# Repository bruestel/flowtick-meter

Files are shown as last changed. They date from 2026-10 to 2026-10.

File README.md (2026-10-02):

# flowtick-meter

**A battery-free optical reader for water meters with a scanning disc.**

Many mechanical water meters carry a small disc in their register that turns
with the flow (half mirror-bright, half black) so that a plug-in module can
count its revolutions. The vendor's pulse modules run on a glued-in lithium cell
and are thrown away when it is empty. flowtick-meter replaces such a module with
a 3D-printed case holding a **Vishay TCRT5000L** reflective sensor and an
**ESP32-C6**, powered over USB. Every bright/dark edge of the disc is one *tick*
of a fixed volume; the reading goes to **MQTT / Home Assistant** and a built-in
web interface.

<p align="center">
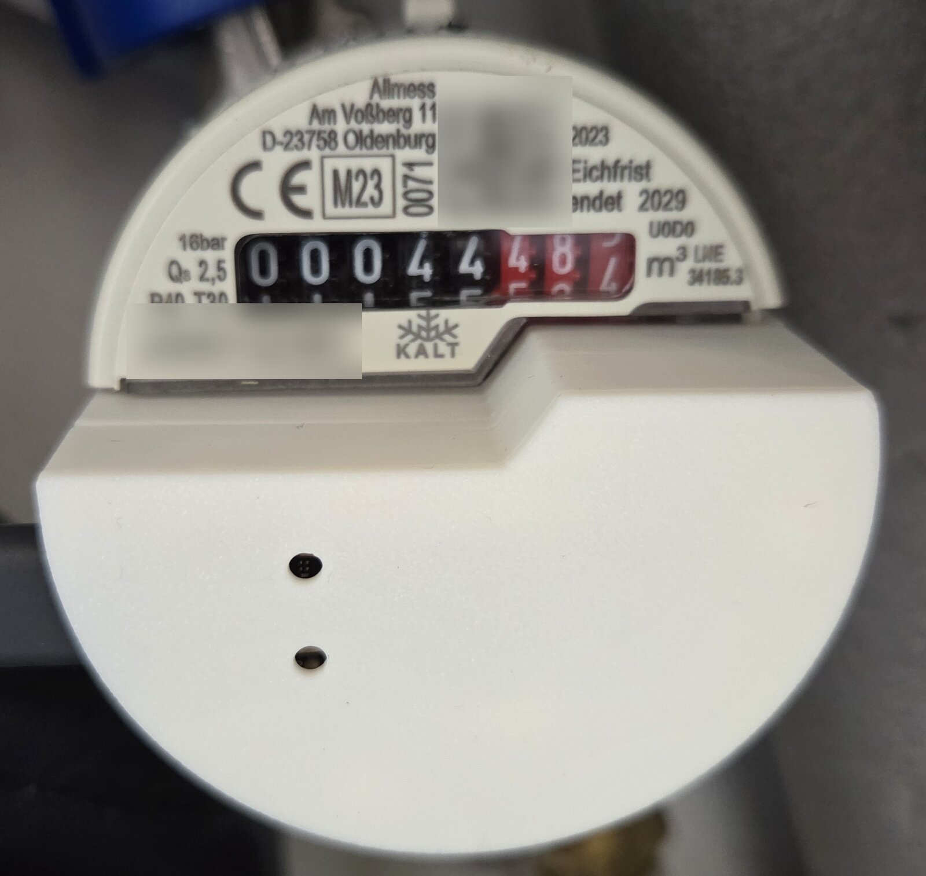
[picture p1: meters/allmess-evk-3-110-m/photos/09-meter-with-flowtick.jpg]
flowtick-meter mounted on an Allmess EVK 3/110 +m
  
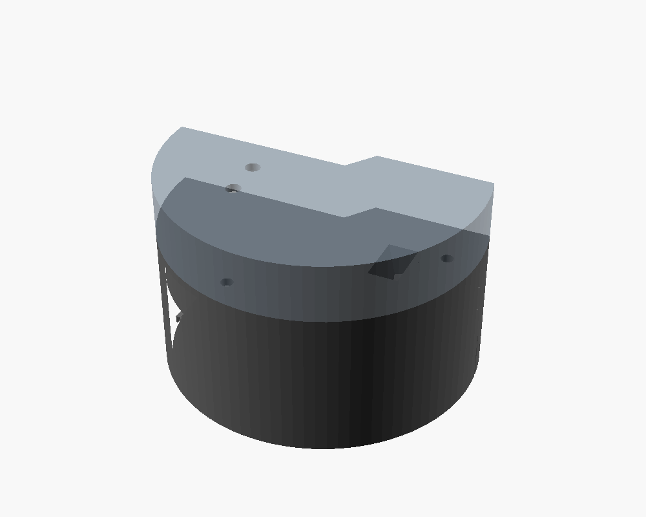
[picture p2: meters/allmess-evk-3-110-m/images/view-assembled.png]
Adapter and cap, CAD model
  
</p>

## How it works

The sensor over the chrome and the black sector, and the resulting signal

```mermaid
flowchart LR
  disc(["Scanning disc<br/>half chrome, half black"]) -- "IR light" --> sensor["TCRT5000L<br/>reflective sensor"]
  sensor -- "voltage" --> mcu["ESP32-C6<br/>ADC at 100 Hz"]
  mcu --> det{{"Edge detector<br/>hysteresis, dwell,<br/>plausibility"}}
  det -- "edge = 0.5 L" --> total["Reading<br/>and flow"]
  total --> ha["MQTT<br/>Home Assistant"]
  total --> web["Web UI"]
  total --> log[("Edge log<br/>in flash")]
```

The sensor sits a few millimetres above the disc. Chrome reflects the IR LED
into the phototransistor, black does not; the voltage swings by about 2.4 V.
The firmware turns that into edges, counts them and keeps the reading across
restarts. Details: [docs/how-it-works.md](docs/how-it-works.md).

One revolution of the disc on a real meter, as the built-in scope shows it:
chrome at ~3 V, black at ~0.5 V, both thresholds dashed, every detected edge
as a green line.

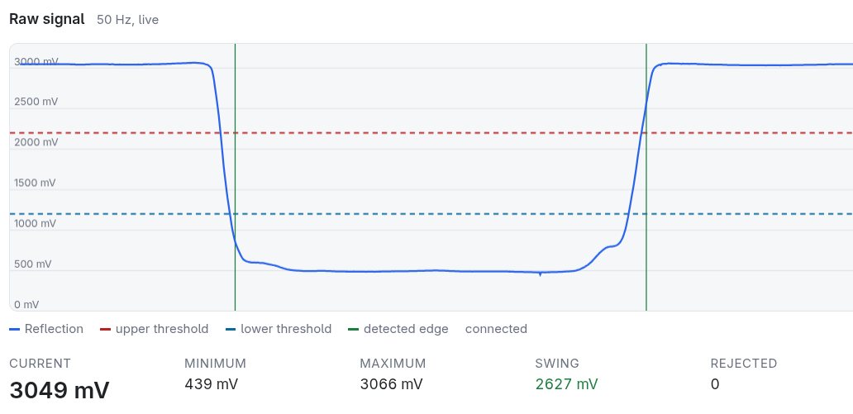
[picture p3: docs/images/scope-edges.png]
Live scope in the web interface: one revolution with two detected edges


## Features

- **Web interface**: reading, flow, water draws, a **live oscilloscope** of the
  raw sensor signal for tuning, all settings; every tab has its own URL.
- **Robust edge detector**: two thresholds (hysteresis), a dwell time against
  spikes, a minimum gap between edges, and a fault mode: a removed adapter or
  light falling in stops counting, and on return the detector resynchronises
  without inventing an edge.
- **Edge log**: every edge with its time in a flash ring that survives power
  cuts, written append-only so it does not wear out the flash; CSV export.
- **Reading kept safe**: saved once a minute when it changed and before every
  restart.
- **WiFi setup**: captive portal on first start; network changes are tested
  before they are stored, and the page follows the device to its new address.
- **OTA updates** with automatic rollback, from the web UI or `curl`.
- **MQTT** with `mqtt://` or `mqtts://` (built-in public CAs, own CA, or
  unchecked), optional login, **Home Assistant discovery**: meter reading for the
  energy dashboard, flow, a *Continuous flow* leak warning and a status entity
  with device diagnostics.
- **Time** from a configurable NTP server with a built-in fallback, timezone
  selectable.

## Supported meters

| Meter | Interface | Volume per edge | Status |
|---|---|---|---|
| [Allmess EVK 3/110 +m](meters/allmess-evk-3-110-m/) | `+m` module bay, optical scanning disc | 0.5 L | working |

The same module bay is used across the Allmess `+m` family, so other meters of
that family very likely fit the same case. Another meter? See
[docs/adding-a-meter.md](docs/adding-a-meter.md).

## Quick start

1. **Get the parts**: ESP32-C6 Super Mini, TCRT5000L, two resistors, black
   PETG; list in [docs/hardware.md](docs/hardware.md).
2. **Solder** the sensor circuit: [docs/hardware.md](docs/hardware.md),
   schematic in [docs/schematic.png](docs/schematic.png).
3. **Print the case** for your meter from [`meters/`](meters/), e.g.
   [meters/allmess-evk-3-110-m/](meters/allmess-evk-3-110-m/).
4. **Build and flash** the firmware: [docs/firmware.md](docs/firmware.md).
5. **Connect** to the `flowtick-xxxxxx` network, enter your WiFi, then
   **tune** thresholds and set the reading: [docs/tuning.md](docs/tuning.md).
   For a supported meter the tested values can be used as they are.

## Repository layout

```
.
├── docs/                  how it works, hardware, firmware, tuning, new meters
├── firmware/              ESP-IDF firmware (C++20, PlatformIO) and web UI
└── meters/
    └── allmess-evk-3-110-m/
        ├── cad/           OpenSCAD source of the case
        ├── stl/           ready-to-print parts
        ├── images/        renders
        └── photos/        photos of the build and the meter
```

## Contributing

New meters, fixes and measurements are welcome, see
[CONTRIBUTING.md](CONTRIBUTING.md).

## Licence

[Apache License 2.0](LICENSE) for everything in this repository: firmware, CAD
models, documentation and images. Copyright 2026 Jonas Brüstel. Firmware images
also contain third-party components, listed in
[THIRD-PARTY-NOTICES.md](THIRD-PARTY-NOTICES.md).

flowtick-meter is not affiliated with or endorsed by any meter manufacturer.
Brand and model names are used only to say which meter a part fits.

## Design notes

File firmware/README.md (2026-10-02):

# flowtick-meter firmware

ESP-IDF firmware for the flowtick-meter reading head: an ESP32-C6 samples a
reflective sensor over the scanning disc of a water meter, counts the edges
and publishes reading, flow and status over a web interface and MQTT.

Networking, configuration, MQTT, the web interface, OTA with rollback,
watchdog, coredump and the BOOT-button recovery are infrastructure taken from
the author's bsh-dbus-idf project; the meter, the edge log and the API on top
are this project's own.

This file is the developer view. For users:

* [../docs/firmware.md](../docs/firmware.md): web interface, MQTT, LED, edge log
* [../docs/tuning.md](../docs/tuning.md): thresholds, edge filter, volume per edge
* [../docs/hardware.md](../docs/hardware.md): board, sensor circuit, wiring

## Building

```bash
pio run -e supermini-c6            # build
pio run -e supermini-c6 -t upload  # flash
pio device monitor
```

Flash size is pinned to 4 MB (`board_upload.flash_size` /
`board_build.flash_size`); without it the upload writes an 8 MB header and the
bootloader asserts. Flash directly, not behind a chain of USB hubs.

The firmware version (web UI, MQTT status, Home Assistant) comes from
`git describe --tags --always --dirty` in a git checkout, and from
`version.txt` otherwise (e.g. a source archive). Bump it with every release.

The project name in the image (`project(flowtick-meter)` in `CMakeLists.txt`)
is checked on OTA: an image of another project is refused.
`same_project()` in `app_web` also accepts the former name `water-meter`, so
devices flashed before the rename update over the air.

Afterwards, OTA from the web UI or:

```bash
curl -X POST -H 'Content-Type: application/octet-stream' \
     --data-binary @.pio/build/supermini-c6/firmware.bin http://<ip>/api/v1/ota
```

ESP-IDF 6.0.1 via `espressif32@7.0.1`. On the first build the component
manager fetches cJSON, esp-mqtt and mDNS, pinned by `dependencies.lock`.

Configuration is **not** compiled in: on first boot the device opens its own
WiFi network and serves a captive portal. Enter WiFi and MQTT there; after
that everything goes through the web interface or OTA.

## Components

| Component | Purpose |
|---|---|
| `app_net` | WiFi station with AP fallback, captive portal, scan and test-before-store connect, transmit power, SNTP (configurable server + built-in fallback, timezone) |
| `app_config` | settings in NVS, PBKDF2 password (stored as one atomic entry) |
| `app_mqtt` | MQTT / MQTTS (built-in CA bundle, own CA or unverified), HA auto-discovery, LWT |
| `app_web` | HTTP, auth, **OTA with rollback**, WebSocket, the REST API |
| `meter` | ADC, edge detection, register, leak watch, NVS |
| `edgelog` | append-only ring of edges in the `edgelog` flash partition |
| `src/` | `main.cpp` wiring, board pins, status LED, diagnostics, BOOT-button recovery, the trial period of a new image (`probation`) |

WiFi power save is off while the scope runs. The default device name is
`flowtick-xxxxxx` from the last three MAC bytes; the Home Assistant device
identity stays `water-meter-xxxxxx` (`appcfg::device_id()`) so devices from
before the rename keep their entities.

## Edge detector

Hysteresis alone is not enough. On top of `thr_hi_mv`/`thr_lo_mv`
(defaults 2200/1200 mV, tuned for the first meter; see
[../docs/tuning.md](../docs/tuning.md)):

* **dwell** (`dwell_ms`, default 80): a crossing counts only once the signal
  has stayed beyond the threshold that long; shorter ones count as `rejected`.
* **minimum gap** (`min_edge_ms`, default 150): faster edges are physically
  impossible (Q4 = 3.1 m³/h at 0.5 L/edge is 0.58 s apart).
* **plausibility**: outside 50..3250 mV for 0.5 s the mode becomes `Fault`
  and nothing counts; after 2 s of plausible signal it goes to `Resync`,
  which waits until the signal is clearly beyond one threshold for `dwell_ms`,
  takes that as the current sector without counting, then `Run`. Between the
  thresholds nothing is decided, so a half-fitted adapter or a disc parked on
  the boundary costs at most one missed edge, never a phantom one.
* **pause** (`POST /api/v1/meter/pause`): `Paused`, e.g. to take the adapter
  off; resuming goes through `Resync`, so reattaching cannot produce an edge.

The detector also starts in `Resync`, so a reboot never creates a phantom
edge. Volume per edge (`ml_per_edge`, default 500) depends on the meter: the
first one turns its disc once per litre, and both edges count.

**Leak watch:** a *run* is a series of edges with never 10 minutes of quiet
between them. Once the edges of one run span an hour, `continuous_flow` is
set (published as a `binary_sensor`); 10 quiet minutes clear it. The flow
figure alone cannot do this: with 0.5 L per edge and a 10 s window it is 0 or
≥ 3 L/min, so a dripping tap stays invisible in it.

## Edge log

The `edgelog` partition (256 KB at 0x380000) is a ring of 4 KB sectors of
8-byte slots: `type | 48-bit payload | crc8`. Edges are stored as uptime ms;
one boot record per boot and one epoch record once SNTP has set the clock,
so edges before time sync still get wall-clock time. Append-only, a sector is
erased only when the ring comes round again, a torn slot fails its crc and is
skipped. Capacity ~32 700 edges (~16 m³). Writes go through a queue to a task
of their own, so the sampler never blocks on flash.

## The live oscilloscope

The WebSocket carries ADC samples from a ring buffer with replay: a reconnect
continues the graph instead of clearing it. Opening the Tuning tab starts a
fresh trace (it asks for no replay), so nothing from before is shown.

In the **Tuning** tab you see the raw signal in real time, with both
thresholds as dashed lines, every detected edge as a vertical stroke and
rejected crossings marked at the top. The stream only runs while the tab is
open, at 50 Hz.

What it took to make it smooth:

* up to 10 samples (100 ms) bundled into one JSON array frame, `TCP_NODELAY`
  set in the pre-handshake callback;
* every client gets its own refcounted payload copy via
  `httpd_ws_send_data_async`, at most 8 in flight; a failed send closes the
  client;
* `send_wait_timeout` 3 s (was 20) and TCP keepalive, so a stalled browser
  tab can block neither other clients nor OTA;
* WiFi power save off while the scope is on;
* the UI plays out on its own clock 300 ms behind the device timestamps and
  draws against a time axis; a watchdog reconnects after 3 s of silence.

## Web UI

Tabs **Meter** (reading, flow, water draws from the edge log with CSV export),
**Tuning** (scope, current/min/max/swing/
rejected, thresholds, edge filter, volume per edge), **Settings** (pause card,
match register, WiFi dialog, MQTT, radio transmit power with Apply, time server
and timezone, device name, auth) and
**System** (status LED legend, OTA, state, restart, factory reset).

WiFi change is test-before-store: from the setup network the device tries the
credentials, reports the new IP in `net.test`, stores and restarts after
30 s. From an existing network it probes the new one, returns to the old one
to report the IP (the networks may be on different subnets), then commits
after 12 s. The UI redirects to the new IP in both cases.

## Time

SNTP starts once the station has an address. Server from the settings
(default `pool.ntp.org`), with a built-in one always behind it
(`time.cloudflare.com`, or `pool.ntp.org` when that is the configured one);
left empty, both slots are built in. Synced every hour. The device counts in
UTC; the timezone (IANA name for the browser, POSIX rule for `TZ`) only sets
how times are shown. The server that last answered is reported in
`/info` → `time.server` and in the MQTT status.

## MQTT

Topic root `<base>` from the settings, default `flowtick/<device name>`.

| Topic | Retained | Content |
|---|---|---|
| `<base>/status` | yes | `online` / `offline` on change and every minute; LWT. `offline` while the detector is in `Fault`, and ~45 s after the device vanishes (keepalive 30 s) |
| `<base>/state/total` | yes | reading in m³, every 10 s |
| `<base>/state/flow` | yes | L/min over the last 10 s, every 10 s |
| `<base>/state/continuous_flow` | yes | `On` / `Off`, every 10 s |
| `<base>/sensor` | yes | JSON every minute: `mode`, firmware, uptime, boot reason, heap, network (hostname, SSID, RSSI, channel, TX power, MAC, IP, netmask, gateway, DNS), time (synced, server, timezone) |

With discovery on, Home Assistant gets one device with *Meter reading*
(`water`, `total_increasing`), *Flow*, *Continuous flow* (`problem`) and a
diagnostic *Status* whose attributes are the JSON above. Values are always
published; whether they are current is what `<base>/status` says; an empty
retained payload would erase the reading at the broker.

## Status LED

One LED (GPIO15), pattern repeats every 10 s: 1 flash online, 2 flashes WiFi
configured but not connected, 3 flashes online but sensor signal
implausible; plus one short flash per edge. Solid = booting / erase armed,
5 Hz = setup network, mostly-on = OTA, 10 Hz = fatal. See
[`src/indicator.h`](src/indicator.h).

## API

All endpoints honour the configured basic auth (off by default).

| Method | Path | Purpose |
|---|---|---|
| GET | `/` | the web interface |
| GET | `/api/v1/info` | overall status: `firmware`, meter (incl. `online`, `mode`, `rejected`, `dwell_ms`, `min_edge_ms`, `continuous_flow`, `flow_run_s`), net (incl. `test`), system (`tx_power_dbm`, `ntp_server`, `tz_name`), time, mqtt |
| GET | `/api/v1/meter` | reading, flow, raw value |
| POST | `/api/v1/meter/total` | `{"m3":44.2670}`: match the mechanical register |
| POST | `/api/v1/meter/pause` | `{"on":true\|false}`: stop / resume counting |
| GET | `/api/v1/edges?limit=N` | edge log, oldest first: `[[t_ms, synced, boot], …]` (default 2000, `0` = all) |
| DELETE | `/api/v1/edges` | erase the edge log |
| GET | `/api/v1/tuning` | current tuning |
| POST | `/api/v1/tuning` | `{"thr_hi_mv":…,"thr_lo_mv":…,"ml_per_edge":…,"dwell_ms":…,"min_edge_ms":…}`, missing fields unchanged |
| POST | `/api/v1/minmax/reset` | restart the swing window |
| POST | `/api/v1/scope` | `{"on":true}`: live stream |
| GET | `/api/v1/samples?since=N` | pull the ring instead of having it pushed |
| GET | `/api/v1/ws` | WebSocket: sample stream |
| GET | `/api/v1/wifi/scan` | networks in range, strongest first |
| POST | `/api/v1/wifi/connect` | `{"ssid":…,"password":…}`: test, then store (see above); progress in `/info` → `net.test` |
| GET/POST | `/api/v1/config/mqtt` | MQTT settings: `enabled`, `host`, `port`, `tls`, `tls_insecure`, `ca_cert` (empty with TLS = built-in CA bundle), `client_id`, `auth`, `user`, `password` (absent = unchanged), `base`, `discovery`, `discovery_prefix` |
| POST | `/api/v1/config/device` | `{"name":…}`: device / host name |
| POST | `/api/v1/config/auth` | `{"enabled":…,"user":…,"password":…}`: web UI auth |
| POST | `/api/v1/config/system` | `{"tx_power_dbm":17}`: transmit power (0 = maximum); `{"ntp_server":"pool.ntp.org","tz_name":"Europe/Berlin","tz_posix":"CET-1CEST,M3.5.0,M10.5.0/3"}`: time server (empty: built-in only; a built-in fallback always stands behind it) and timezone (name and POSIX rule together) |
| POST | `/api/v1/ota` | firmware.bin as `application/octet-stream`; header `X-Confirm: ui` when the caller will confirm the new image itself |
| GET | `/api/v1/ota/status` | running slot and version, `pending_verify`, `ui_confirmed`, and during the trial period `probation` (`uptime`, `sampler`, `network`, `web_server`, `page_needed`, `page`, `left_s`, `window_s`) |
| POST | `/api/v1/ota/confirm` | the update page confirms the new image (see [../docs/firmware.md](../docs/firmware.md#updates-and-rollback)) |
| GET | `/api/v1/selftest` | `{"ok":true}`, answered only over loopback for the image's self-test; 404 from anywhere else |
| POST | `/api/v1/restart` | restart |
| POST | `/api/v1/reset` | factory reset |
| GET | `/api/v1/health` | tasks, stack, heap, reset reason |
| GET/DELETE | `/api/v1/coredump` | download / erase the stored coredump |

## Decisions

**Oneshot ADC instead of continuous/DMA.** At Q3 = 2.5 m³/h the flow is at most
41.7 L/min; at 0.5 L per edge that is ~1.4 edges per second. 100 Hz is a
factor of 70 above that. DMA would mean a ring buffer and interrupt handling
for a signal that changes about once a second.

**Median over 8 samples, not the mean.** The median kills single outliers
without smearing the edge. A mean would blur exactly the edge that matters.

**`CONFIG_FREERTOS_HZ=1000`.** Not optional. At the default of 100 Hz the tick
resolution would equal the sampling period, and the jitter would be 100 %.

**Reading written to NVS once a minute if it changed, not per pulse.** Per
pulse the flash would be worn out within months; once a minute is about two
erases per NVS page and day even with water running non-stop (~135 years to
100 000 cycles). Cost: at most a minute of consumption on a power cut. Before
every deliberate restart (OTA, restart, recovery) it is written as well.

**Reading saved before every deliberate restart.** A shutdown handler in
`meter` writes it from `esp_restart()`. Without it every OTA lost up to the
last save interval, and Home Assistant reads a reading that went backwards
(`total_increasing`) as a meter swap.

**Reading as `uint64` in millilitres.** `uint32` would overflow at ~4,294 m³.
For a project meant to outlive several meter generations, not a theoretical
problem.

**Thresholds are rejected if `thr_hi <= thr_lo`.** Such a hysteresis is none:
it would flip on every sample and drive the counter up by cubic metres within
seconds. Better to reject than to puzzle later over where the consumption came
from.

## Pinout

See [`src/board.h`](src/board.h). In short: ADC on **GPIO1**, status LED
GPIO15, BOOT GPIO9, IR LED tied to 3V3.

On the C6, ADC1 sits on GPIO0..GPIO6 and there is no ADC2; of those, only
GPIO0..GPIO3 are broken out on the Super Mini and free of boot duties.

`LED_ACTIVE_LOW` is verified as `false` (active high) on this board. The Super Mini clones are not consistent
about it. If the LED blinks inverted, it is this switch and nothing else.

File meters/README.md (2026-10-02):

# Meters

One folder per meter model. Each folder holds what is specific to that meter:
the case that fits its module bay and the sensor values that make it read
reliably. Everything else (circuit, firmware, tuning) is shared and lives in
[`docs/`](../docs/) and [`firmware/`](../firmware/).

## Supported

| Folder | Meter | Volume per edge | R1 / R2 | Status |
|---|---|---|---|---|
| [allmess-evk-3-110-m](allmess-evk-3-110-m/) | Allmess EVK 3/110 +m (cold water) | 0.5 L | 560 Ω / 1.56 kΩ | working |

## Folder structure

```
meters/<vendor>-<model>/
├── README.md     meter data, module bay, measurements, tested values
├── cad/          parametric source of the case (OpenSCAD preferred)
├── stl/          exported parts, ready to print
├── images/       renders of the case
└── photos/       reference photos (metadata stripped)
```

Folder names are lower case, words separated by hyphens:
`<vendor>-<model>`, e.g. `allmess-evk-3-110-m`.

How to add one: [docs/adding-a-meter.md](../docs/adding-a-meter.md).

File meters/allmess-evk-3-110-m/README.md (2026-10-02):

# Allmess EVK 3/110 +m

Cold water meter by Allmess with a **+m module bay**: a standard slot for a
plug-in communication module (pulse, M-Bus or wireless M-Bus), fitted without
removing the meter or touching its calibration. As delivered, the bay holds a
**blank module** ("Leermodul") that is just a dust cover. The flowtick-meter
case replaces it: a printed adapter in the shape of the blank module, carrying
the reflective sensor over the scanning disc and the ESP32-C6 Super Mini in
front of it.

**Status:** printed and running. The snap fit was verified with fit tests on
the real meter, and the counting matches the mechanical register.

| flowtick-meter on the Allmess EVK 3/110 +m | Adapter and cap, assembled |
|---|---|
| on the meter | the CAD model |

## The meter

| | |
|---|---|
| Meter | Allmess EVK 3/110 +m, cold water |
| Interface | +m module bay, optical (no magnet, no reed contact) |
| Scanning disc | under the clear window to the right of the roller register, **half chrome, half black** |
| Disc ratio | dial marked **x0,0001**: 1000 revolutions per m³ = **1 L per revolution** |
| Edges | 2 per revolution (chrome→black, black→chrome) = **0.5 L per edge** |
| Original pulse module (PM +m) | at best 1 L per pulse, battery for ~13 years |

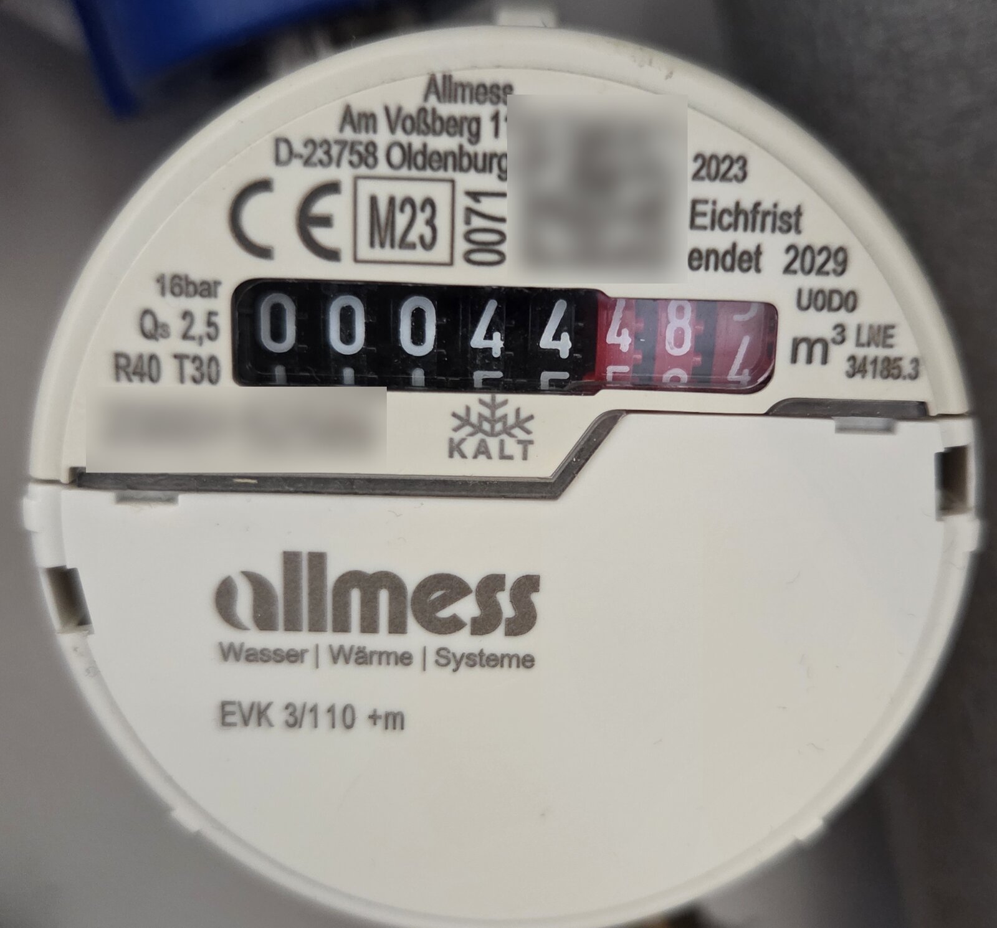
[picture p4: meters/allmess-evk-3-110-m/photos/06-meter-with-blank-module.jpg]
With the blank module
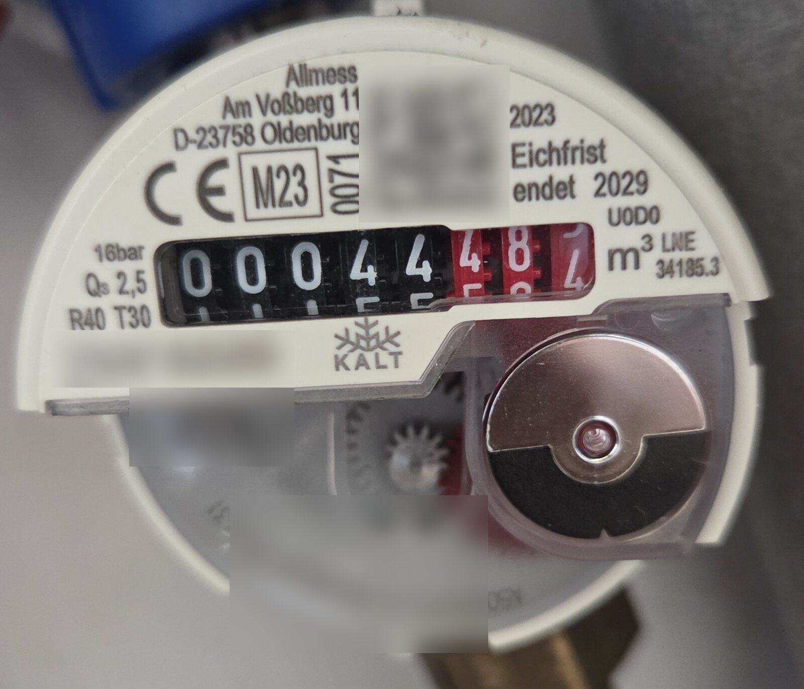
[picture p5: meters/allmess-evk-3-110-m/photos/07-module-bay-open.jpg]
Module bay open
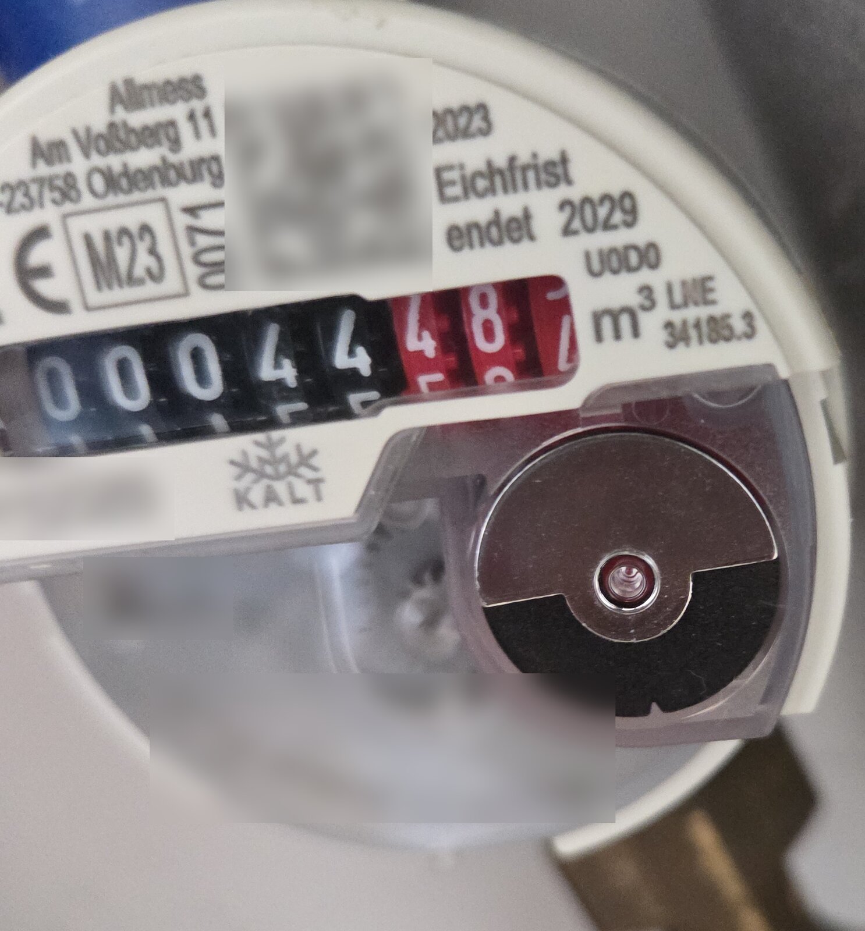
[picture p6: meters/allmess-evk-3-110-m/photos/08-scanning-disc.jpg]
The scanning disc
|  |  |  |
|---|---|---|
| as delivered, with the blank module | blank module removed: the disc sits under the clear window | the disc, half chrome, half black |

The +m register is the same across the Allmess family (EVK, EV, WTZ,
System-V, System-MK, AMES measuring capsule): same bay, same snaps, same
disc. A case built once also fits the meter that replaces this one when its
calibration period runs out.

**Before you start:** taking the blank module off tears the name plate at its
perforation and cannot be undone. If the meter belongs to the utility or the
landlord, your own hardware in the module bay may count as tampering with a
calibrated device; ask first.

## The module bay

The adapter replaces the blank module that sits in the bay when no
communication module is fitted. Its outline is a copy of that blank module,
taken from a flatbed scan. Only the round wall touches the meter; the clear
window over the disc pokes past the straight edge, which is what the nose of
the case is for. All dimensions are parameters in
[`cad/housing.scad`](cad/housing.scad).

## The case

Two parts, joined by two screws, both printable **without support**. Source:
[`cad/housing.scad`](cad/housing.scad) (OpenSCAD, fully parametric).

| Part | `part=` | What it does | Print orientation |
|---|---|---|---|
| **Adapter** | `adapter` | copy of the blank module: round wall, snap tongues, sensor sleeve | front face down |
| **Cap** | `cap` | compartment for the Super Mini, sits on the front of the adapter | lid down |

| Adapter front | Without the cap | Laid out for printing |
|---|---|---|
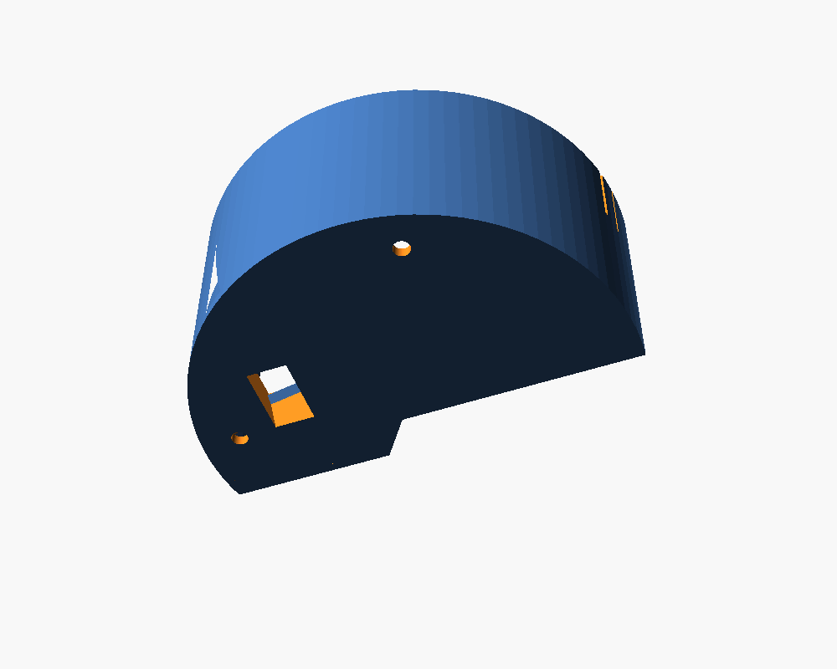
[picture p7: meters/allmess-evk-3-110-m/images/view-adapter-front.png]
Adapter front
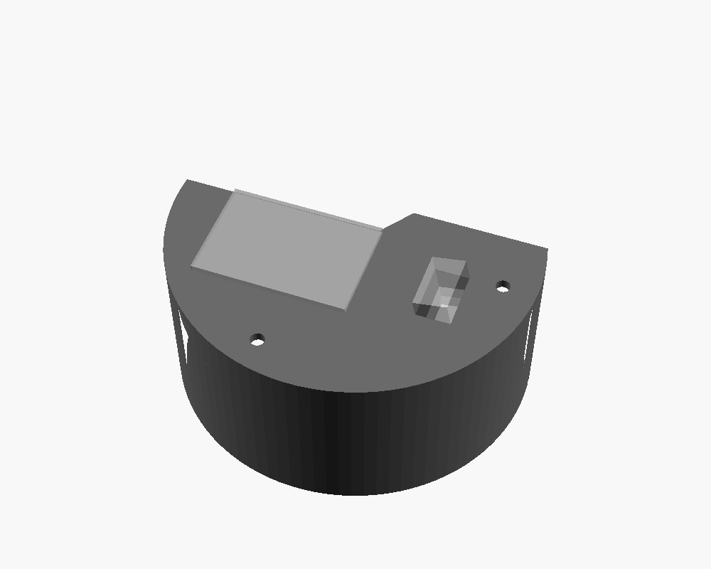
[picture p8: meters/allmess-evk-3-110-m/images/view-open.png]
Board and sensor outlines
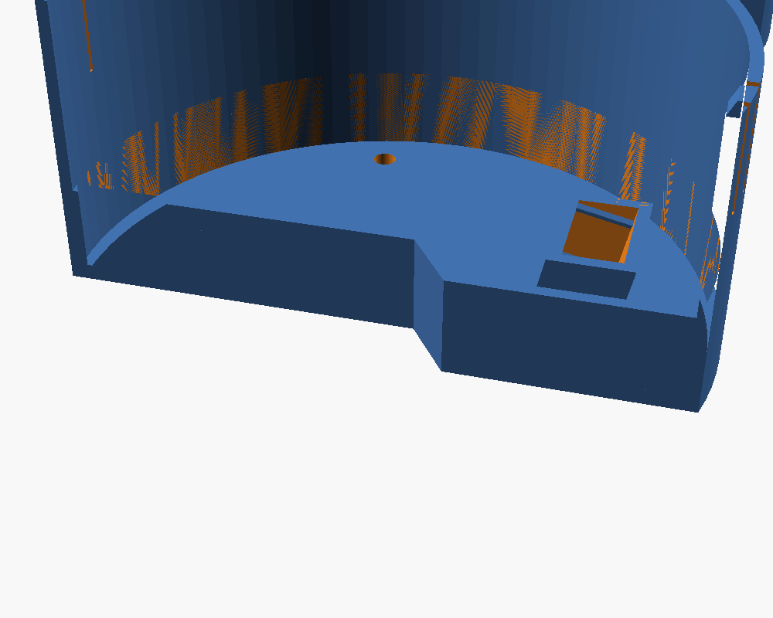
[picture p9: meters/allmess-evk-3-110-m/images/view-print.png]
Print layout
|  |  |  |

### Adapter

* **6 mm deeper than the original** (`lift`, 29.5 instead of 23.5 mm). The
  front plate moves out; the rim against the meter and the snap tongues stay
  where the original had them.
* **Sensor sleeve** in the 6 mm gained, from the front plate backwards, ending
  where the floor of the original was, right in front of the window. The
  TCRT5000L peaks at 2.5 mm and the window is ~5 mm behind the original front
  plate, so the sensor has to reach in. It sits 4.5 mm below the disc centre
  (`sensor_off`, `sensor_dir = -90`), lens axis radial, so both lenses see the
  rotating sectors, and is **tilted 12°** about the lens axis (`tilt`) so the
  direct reflection off the window misses the phototransistor.
* **Stop in the sleeve:** two 45° wedges (`stop`, 1 mm) at the short ends. The
  narrow lens end (~6.8 mm) passes, the shoulders of the TCRT5000L rest on
  them. The window can push the sensor back, so it finds its own distance.
* **Press fit**, 0.05 mm undersize per side (`press`); find yours with the slot
  test.
* **Rim** along the straight edge, the chamfer and the nose: 4 mm + `lift` from
  the front.
* **Snap tongues** 10 mm long (`slot_depth`; the original ~4 mm ones broke)
  with a 0.8 mm catch (`catch_h`) and a lead-in ramp. The left one sits 1 mm
  further towards the straight edge than the scan, from fit tests.

Switched off, but still in the model as parameters:

| Parameter | What | Why off |
|---|---|---|
| `inner_wall_on` | straight inner wall as on the original | the rim is enough; it gets in the way when fitting |
| `ribs_on` | the three ribs inside | switch on if the adapter wobbles |
| `pocket_wall` | cup around the pocket | the case is black anyway; a slightly misplaced cup would sit on the window |
| `release_windows` | windows over the snap tongues | cannot be reached under the cap |

### Cap

* The Super Mini (26.04 × 18 mm) lies across, **components towards the lid**,
  USB-C to the left, beside the sensor rather than over it; the antenna end
  faces the sensor.
* It hangs in **four corner brackets** from the lid and snaps in past small
  lips (`lip = [0.3, 1.2]`: 0.3 mm undercut, 1.2 mm ramp), 5.3 mm below the
  lid (`board_stand`, room for the plug overmould). Ribs from the lid support
  both pin rows, broken where wires are soldered (GND, 3V3, GPIO1).
* The board sits as far left as the round allows (`board_pos`), leaving 7.2 mm
  between board and sensor sleeve for R1, R2 and C1.
* Opening for the USB-C plug in the left wall (`usb_notch`, 13 × 10 mm), holes
  in the lid for BOOT and RST. The status LED shines through the lid.

### Screws

2 × **M2 × 8 self-tapping**, **from behind** through the adapter front into
bosses in the cap (`screws`): pilot hole 1.7 mm, clearance 2.4 mm, pan or
cheese head up to 4.2 mm (no countersink). The heads sit hidden inside the
adapter and the front stays flat; the price is that the screws go in before
the adapter goes onto the meter.

### Key parameters

| Parameter | Value | Meaning |
|---|---|---|
| `R` | 31.75 | outer radius |
| `D0`, `lift` | 23.5, 6.0 | original depth, extra depth for the sensor sleeve |
| `edge_y` | 2.5 | straight edge above the centre |
| `pocket_c` | [17.83, −2.79] | disc centre |
| `sensor_off`, `tilt` | 4.5, 12 | sensor offset from the disc centre, tilt about the lens axis |
| `press` | 0.05 | sensor slot undersize per side |
| `snap_right`, `snap_left` | see scad | slot and tongue extents along y |
| `slot_depth`, `catch_h` | 10, 0.8 | tongue length, catch height |
| `board_pos`, `board_stand` | [−21.0, −18.8], 5.3 | board corner, lid to board |
| `screws` | [[−7, −25.5], [26, −2]] | screw positions |

## Printing

| | |
|---|---|
| Material | **PETG, black** |
| Layer height | 0.15–0.20 mm |
| Perimeters | **4** |
| Infill | 30 % |
| Support | **none** (adapter front down, cap lid down) |

PETG because the meter pit is damp and can get warm, PLA creeps under
constant load, and PETG is tougher at the snap tongues. Black and 4 perimeters
because many "black" filaments are translucent in the infrared: hold a print
against a bright torch, and if light comes through, print thicker or paint the
inside matt black.

### Print the test parts first

| `part=` | What | What for |
|---|---|---|
| `slot-test` | three sensor slots, undersize −0.05 / 0.05 / 0.15 mm, marked with 1/2/3 notches | the right one takes the sensor with firm pressure and holds it upside down; put its value into `press` |
| `snap-test` | the lowest ring of the adapter with both snap tongues | prints in minutes; try it on the real meter and tune `catch_h` and the tongue positions |

### Rendering the STLs

Ready-made STLs are in [`stl/`](stl/). To render them yourself (tested with
OpenSCAD 2021.01):

```sh
cd meters/allmess-evk-3-110-m
openscad -o stl/adapter.stl   -D 'part="adapter"'   cad/housing.scad
openscad -o stl/cap.stl       -D 'part="cap"'       cad/housing.scad
openscad -o stl/slot-test.stl -D 'part="slot-test"' cad/housing.scad
openscad -o stl/snap-test.stl -D 'part="snap-test"' cad/housing.scad
```

`part="print"` lays out adapter and cap side by side, `both` shows them
assembled, `open` without the cap (board and sensor as outlines).

## Assembly

1. Wire the sensor and resistors, see [hardware](../../docs/hardware.md).
2. Push the board into the cap until it snaps in past the lips.
3. Push the sensor into the sleeve of the adapter from the front, lenses
   first, until it rests on the wedges. Lead the wires to the board.
4. Put the cap on and drive the two M2 × 8 **from behind** through the adapter
   front into the bosses.
5. Push the adapter onto the register until both tongues snap in. The window
   pushes the sensor back in its sleeve until it touches.

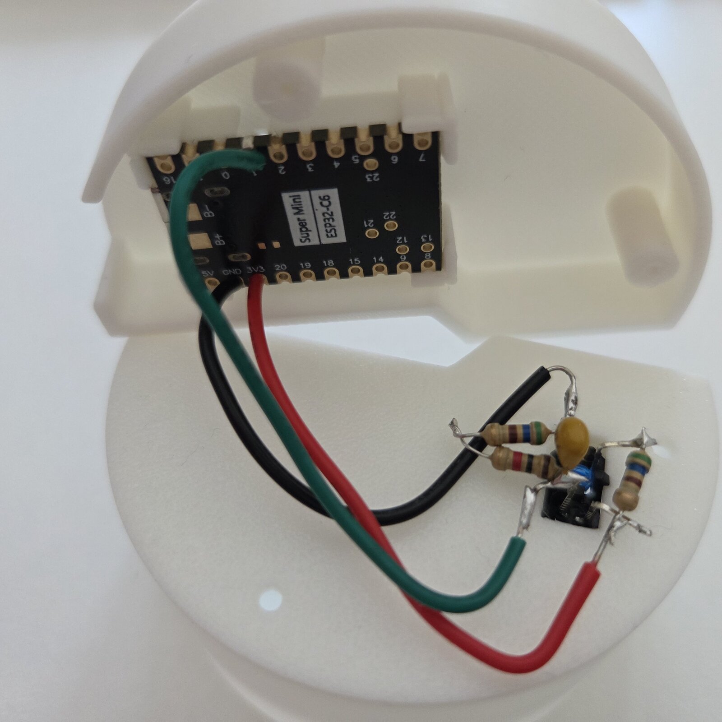
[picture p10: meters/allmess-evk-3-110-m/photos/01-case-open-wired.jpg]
Case open, wired
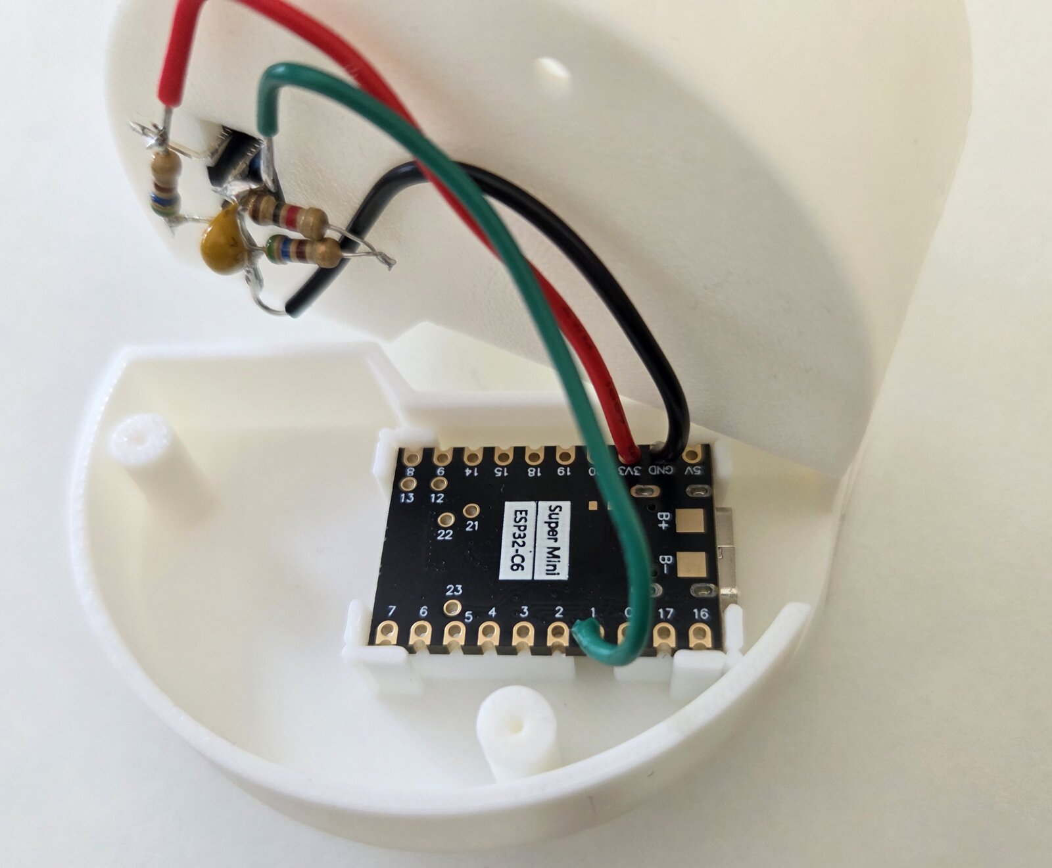
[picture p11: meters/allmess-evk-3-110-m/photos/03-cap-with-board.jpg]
Cap with the board
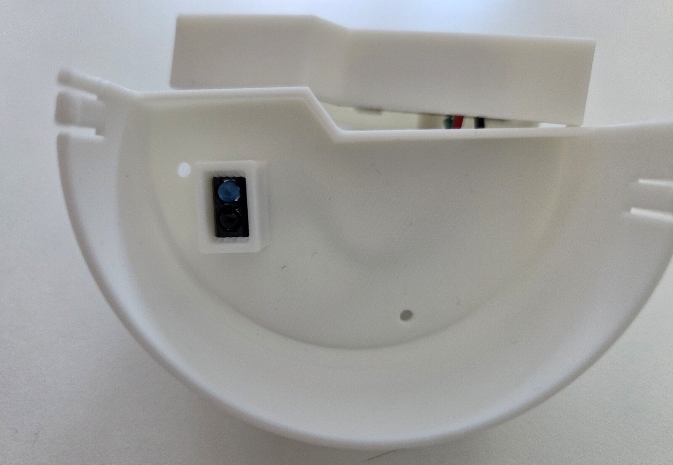
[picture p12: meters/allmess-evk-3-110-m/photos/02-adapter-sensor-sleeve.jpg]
Sensor in its sleeve
|  |  |  |
|---|---|---|
| wired: board in the cap, sensor with R1/R2 in the adapter | board snapped in between the corner brackets | sensor sitting in the sleeve |
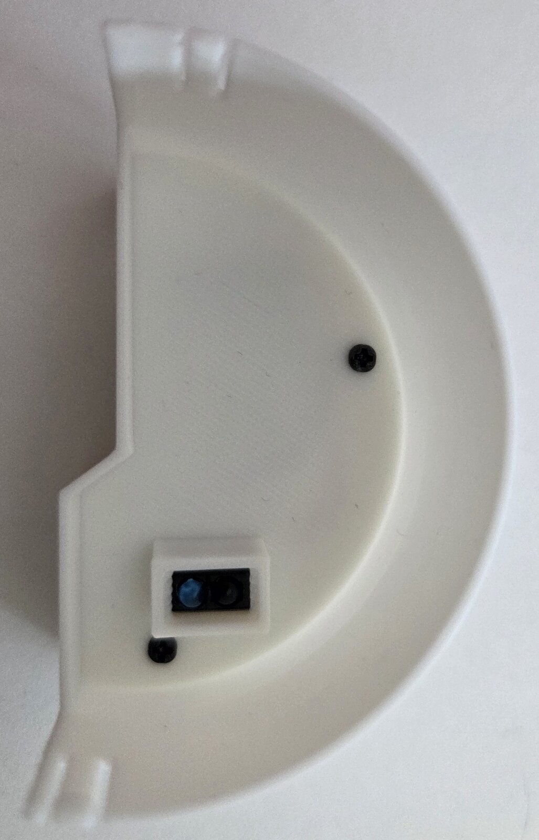
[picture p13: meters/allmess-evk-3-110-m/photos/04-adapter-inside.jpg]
Adapter, inside
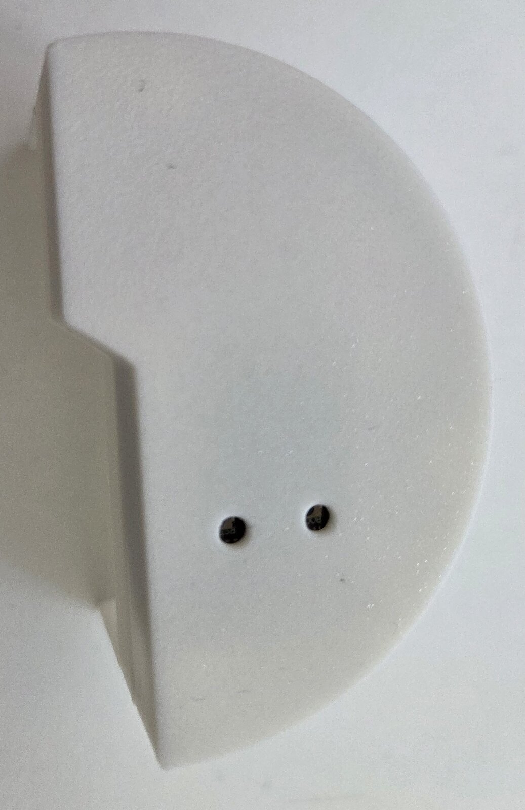
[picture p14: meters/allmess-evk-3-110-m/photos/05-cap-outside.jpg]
Cap, outside
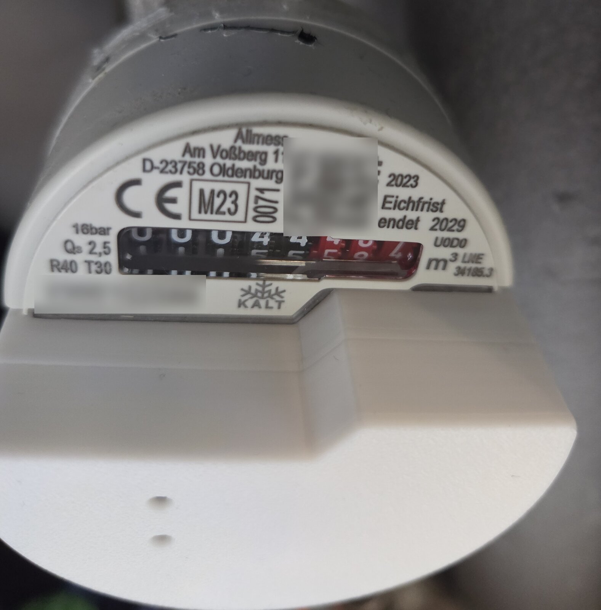
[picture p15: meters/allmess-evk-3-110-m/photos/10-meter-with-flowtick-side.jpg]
Mounted, side view
|  |  |  |
| adapter from behind: sensor sleeve and the two screws | cap from outside: holes for BOOT and RST | mounted on the meter |

To take it off again, pause counting in the web interface first, see
[tuning](../../docs/tuning.md).

## Tested values

**No changes needed for this meter**: these are the firmware defaults.

| | |
|---|---|
| R1 (IR LED series) | 560 Ω |
| R2 (phototransistor emitter) | 1.56 kΩ (1 kΩ + 560 Ω in series) |
| Signal, black sector | ~500 mV |
| Signal, chrome sector | ~2900 mV |
| Swing | ~2.4 V |
| Thresholds | 2200 / 1200 mV |
| Dwell | 80 ms |
| Minimum gap between edges | 150 ms |
| Volume per edge | 0.5 L |

Scope on this meter: one revolution, swing 2627 mV, no rejected crossings

How these were found, and what to change for another meter, is in
[hardware](../../docs/hardware.md) and [tuning](../../docs/tuning.md).

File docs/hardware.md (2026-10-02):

# Hardware

The electronics are the same for every meter: an ESP32-C6 Super Mini and a bare
Vishay TCRT5000L reflective sensor, plus two resistors. Only the two resistor
values and the printed case change from meter to meter.

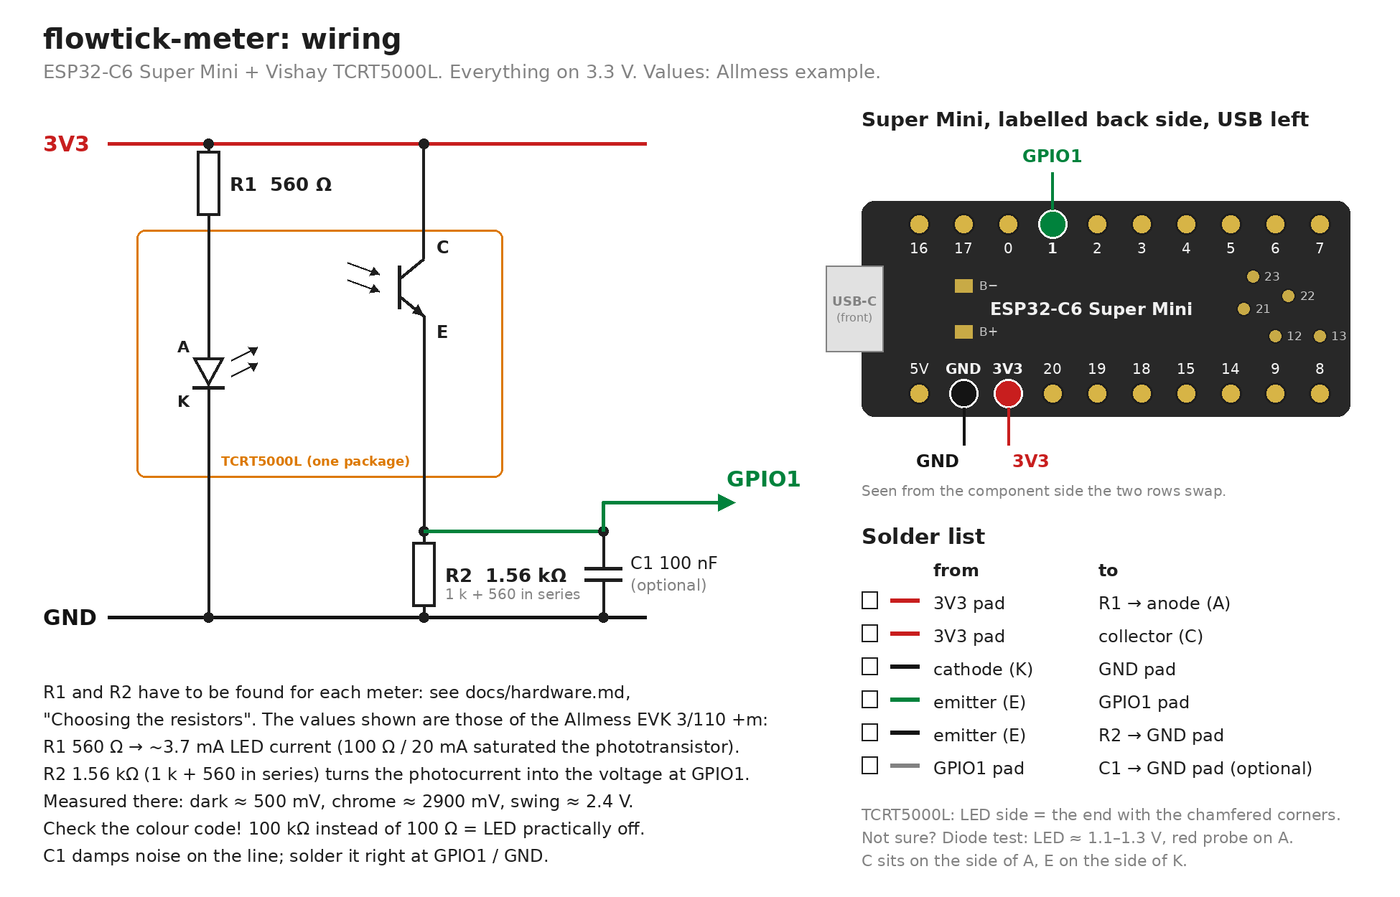
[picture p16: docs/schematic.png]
Circuit, Super Mini pads and solder list


Generated by [`schematic.py`](schematic.py) (`cd docs && python3 schematic.py`,
needs Pillow and the DejaVu fonts). The values shown are those of the
[Allmess EVK 3/110 +m](../meters/allmess-evk-3-110-m/README.md).

## Circuit

* **LED branch:** 3V3 → **R1** → anode (A) → cathode (K) → GND
* **Transistor branch:** 3V3 → collector (C) → emitter (E) → **GPIO1**, and
  from the emitter **R2** to GND
* **C1** (100 nF, optional) right at the board between GPIO1 and GND

**Signal direction:** the bright (chrome) sector reflects a lot, the
phototransistor conducts more, and the voltage at GPIO1 rises. The dark sector
gives a low voltage. The firmware turns every crossing between the two into an
edge; see [tuning.md](tuning.md).

**Everything runs on 3.3 V.** The bare TCRT5000L has no "operating voltage":
it is an IR LED and a phototransistor. The "5 V" in shop listings refers to the
breakout boards with an LM393 comparator. With the collector on 3V3, GPIO1 can
never see more than 3.3 V, and the IR output depends on the current, not on
the voltage.

### ESP32-C6 Super Mini

| Function | Pin |
|---|---|
| ADC input (phototransistor emitter) | **GPIO1** |
| Status LED (active high) | GPIO15 |
| BOOT button | GPIO9 |
| IR LED supply | 3V3 (always on) |

* ADC1 sits on GPIO0–GPIO6; there is no ADC2. The board breaks out GPIO0–3,
  8–9 and 12–23 (plus TX/RX), so GPIO0–GPIO3 are the usable ADC pins.
* Keep clear of GPIO8 (RGB LED), GPIO9 (BOOT), GPIO12/13 (USB D−/D+) and
  GPIO15 (status LED).
* Pad rows as printed on the labelled back side, USB-C on the left:
  top: 16 (TX), 17 (RX), 0, 1, 2, 3, 4, 5, 6, 7;
  bottom: 5V, GND, 3V3, 20, 19, 18, 15, 14, 9, 8.
  Seen from the component side the two rows swap. The back also has B+ / B−
  battery pads and the inner pads 12, 13, 21, 22, 23.
  Only **GND, 3V3** and **GPIO1** are used.

### Why not a TCRT5000 breakout board

The common modules with a potentiometer and an LM393 (32 × 14 mm) are too big
for a meter's module bay, usually only bring out the digital output, and have
barely any hysteresis. Hysteresis, dwell time and plausibility checks are done
in the firmware instead ([firmware.md](firmware.md)). The boards still make
good part donors: desolder the TCRT5000 and use it bare.

## Bill of materials

Per meter:

| Part | Purpose | Notes |
|---|---|---|
| **ESP32-C6 Super Mini** | controller, 4 MB flash | |
| **Vishay TCRT5000L**, through-hole, bare | reflective sensor over the scanning disc | buy a few, one or two tend to die while soldering and fitting |
| **R1** | IR LED series resistor | value per meter, see below |
| **R2** | phototransistor emitter resistor | value per meter, see below |
| C1, 100 nF ceramic | noise filter at GPIO1 | optional |
| thin stranded wire | sensor → board | a few cm, 3 or 4 wires |
| 2 × **M2 × 8** self-tapping screws | cap to adapter | for the Allmess case; other cases may differ |
| **PETG**, black | printed case | black, so no stray light reaches the sensor |
| USB-C cable + 5 V supply | permanent power | |

To find R1 and R2 for a new meter, have a small assortment at hand:
**220 Ω, 560 Ω, 1 kΩ, 2.2 kΩ, 4.7 kΩ, 10 kΩ**. Two in series give the values in
between.

Tools: soldering iron and heat-shrink tubing, a multimeter with a diode test,
calipers, a 3D printer.

## Identifying the TCRT5000L pins

The part is not marked.

* **LED side** = the end with the **chamfered corners**.
* **Diode test** on the LED pair: about 1.1–1.3 V forward, **red probe on the
  anode (A)**. The transistor pair shows no diode drop in either direction.
* **C sits on the side of A, E on the side of K.**
* Check: collector to 3V3, emitter through R2 to GND. Holding white paper
  2–3 mm in front, the emitter voltage has to rise.
* A phone camera often does **not** show the IR LED (many have an IR filter).
  No glow in the picture does not mean it is dead; measure the voltage across
  R1 instead (about 2.1 V with 560 Ω).

## Choosing the resistors

**This is the one part that has to be worked out for every meter.** The sensor
sits at a different distance from the disc, behind a different window, looking
at a disc that reflects differently. A pair of resistors that gives a perfect
signal on one meter can saturate on the next or barely move on a third.

### What each one does

* **R1 sets the LED current**, about `(3.3 V − 1.2 V) / R1`. Smaller R1 → a
  brighter LED → more photocurrent over **both** sectors. 560 Ω gives
  ≈ 3.7 mA, 220 Ω ≈ 9.5 mA, 100 Ω ≈ 21 mA. Do not go below ~100 Ω (≈ 20 mA);
  less current also means less ageing of the LED.
* **R2 turns the photocurrent into the voltage at GPIO1.** Larger R2 → more
  voltage for the same light → more sensitive, again for both sectors.

Both scale the bright and the dark level together. What you are after is the
**gap** between them, inside the window the ADC and the firmware can use.

### The target

| | Target | Why |
|---|---|---|
| dark sector | clearly above **~300 mV** | below that a sensor that came loose looks like "dark"; the plausibility limit is 50 mV |
| bright sector | clearly below **3250 mV**, not saturated | above 3250 mV the firmware treats the signal as implausible (Fault); near 3.3 V the ADC also gets non-linear |
| swing (bright − dark) | **≥ 500 mV**, more is better | the thresholds sit at roughly 30 % and 70 % of it |

**Saturation** looks like this: the bright sector is a flat plateau around
3.1–3.3 V instead of a profile, and changing the light hardly changes the
reading. The swing is then smaller than it could be, and the dark level is
often too high as well.

### Procedure

1. **Start values:** R1 = 560 Ω, R2 = 1.5–2.2 kΩ.
2. Mount the sensor in its case **on the meter**, closed as in use. The
   distance and the stray light are what you are tuning for.
3. Open the web UI, **Tuning** tab, press **Reset min/max**.
4. Let water run (or, on a meter you can turn, turn the disc) for a few full
   revolutions. Read **Min**, **Max** and **Swing**, and look at the live
   trace.
5. Change one resistor, reset min/max, repeat:

| Symptom | Change |
|---|---|
| bright sector flat near 3.1–3.3 V, swing small | saturated: **raise R1** (dimmer LED) or **lower R2** |
| both levels low, small swing | **lower R1** (not below ~100 Ω) or **raise R2** |
| dark level below ~300 mV, bright level fine | small step up in sensitivity (a bit larger R2 or smaller R1), watching that the bright sector does not saturate; the dark level needs headroom above the loose-sensor case |
| noisy trace, spikes | close the case (stray light), fit **C1**, keep the signal wire short |
| no reaction at all | check the LED with the diode test, measure R1 (colour code!), check A/K/C/E |

6. When the levels are right, set the thresholds and the volume per edge:
   [tuning.md](tuning.md).

Values in between come from **two resistors in series**: 1 kΩ + 560 Ω =
1.56 kΩ, 2.2 kΩ + 1 kΩ = 3.2 kΩ.

**Measure every resistor before soldering it in.** The first build here had
100 kΩ (brown black **yellow**) in the LED branch instead of 100 Ω (brown black
**brown**). The LED then gets about 20 µA and stays practically dark, and the
sensor looks broken.

### Worked example: Allmess EVK 3/110 +m

The textbook values were far too sensitive: the chrome sector is a mirror
2–3 mm in front of the sensor.

| R1 | R2 | Result |
|---|---|---|
| 100 Ω | 10 kΩ | chrome 3160–3260 mV, saturated |
| 220 Ω | 2.2 kΩ | still saturated |
| **560 Ω** | **1.56 kΩ** (1 k + 560) | **dark ≈ 500 mV, chrome ≈ 2900 mV, swing ≈ 2.4 V** |

For this meter nothing needs changing: build it with 560 Ω and 1.56 kΩ. The
meter's own page has the rest:
[meters/allmess-evk-3-110-m](../meters/allmess-evk-3-110-m/README.md).

## Wiring in a small case

Space inside a module bay is tight. Two ways to place the resistors:

1. **At the sensor.** Solder R1 and R2 straight onto the sensor legs and
   insulate them with heat-shrink. Only **three wires** run to the board:
   3V3, GND and the signal (emitter). The cleanest option.
2. **On the board side.** R1, R2 (and C1) lie next to the board where the case
   leaves room; four wires (A, K, C, E) run from the sensor.

* Fit **C1**, if used, right at the board between GPIO1 and GND.
* Keep the wires short; at a few centimetres no shielding is needed.
* The board sits in the case component side towards the lid. The stand-off
  ribs in the case are interrupted at the soldered pads (GND, 3V3, GPIO1), so
  the solder joints and wires have room.

## Power

USB-C, 5 V, well under 100 mA. Any phone charger will do; plan for permanent
power, not a battery.

The Super Mini has a green charge LED on BAT that blinks continuously when
running from USB without a battery. It cannot be switched off in software;
desolder it if it bothers you. A resistor between BAT and GND does not help, it
only blinks faster.

## Next

* Firmware, flashing and the web UI: [firmware.md](firmware.md)
* Thresholds, edge filter, volume per edge: [tuning.md](tuning.md)
* Supporting a new meter: [adding-a-meter.md](adding-a-meter.md)

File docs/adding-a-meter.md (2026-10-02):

# Adding a meter

flowtick-meter works with any water meter whose register has an **optical
scanning disc** (a disc that turns with the flow and has a bright and a dark
part) and a place where a sensor can look at it, usually a bay for a
plug-in communication module. Supporting a new meter means two things: a case
that holds the sensor in the right place, and the sensor values that make the
signal clean. This page walks through both.

## 0. Check that the meter qualifies

- Is there a **disc you can see** under a window, next to the number rollers,
  with clearly bright and dark sectors? Magnetic or inductive interfaces do not
  work with this sensor.
- Is there a **module bay** or other mount where something can sit over that
  window without opening the sealed register? Never touch the seals.
- Find out the **volume per revolution** of the disc: often printed next to it
  or on the blank module (e.g. `x0,0001` m³ = 1 L per revolution). With one
  bright and one dark half there are two edges per revolution.

## 1. Measure the module bay

- Take photos straight from above and from each end, with a ruler or calliper
  in the picture. A flatbed scan of the removed blank module at 300 dpi gives
  the outline to a tenth of a millimetre.
- Note: outline, wall heights, where the module snaps or clips in, the position
  of the window over the disc **relative to the bay**, and the distance from
  the bay's front to the disc.
- The TCRT5000L reads best at about **2.5 mm** from the disc (still ~75 % at
  5 mm). Plan for the sensor to end close to the window, not at the front of the
  module.

## 2. Design the case

Create `meters/<vendor>-<model>/` (see [meters/README.md](../meters/README.md))
and start from an existing model, e.g.
[meters/allmess-evk-3-110-m/cad/housing.scad](../meters/allmess-evk-3-110-m/cad/housing.scad).

What has worked well:

- **Two parts**: an adapter that replaces the blank module and holds the
  sensor, and a cap that holds the ESP32-C6 with the USB socket reachable.
- **Black filament** (PETG). Light-coloured plastic lets IR through and lowers
  the contrast.
- A sensor sleeve with stops, so the sensor sits at the right depth by itself;
  a slight tilt (about 10–15°) reduces direct reflection from the window.
- Print small **test pieces** first (sensor slot, snap fit). They take
  minutes, the full case takes hours.
- Keep the board beside the sensor rather than above it, and leave room for the
  two resistors.

## 3. Find the resistors

The LED series resistor **R1** and the phototransistor's emitter resistor
**R2** set the operating point. Every meter differs: the distance to the disc,
the window plastic and the disc finish all change how much light comes back.
Start with the values of a supported meter and follow
[docs/hardware.md → Choosing the resistors](hardware.md#choosing-the-resistors).
The goal is a dark level well above 0 V and a bright level clearly below the
3.3 V rail, with as much swing between them as possible.

## 4. Tune the detector

With the sensor in the case on the meter, open the **Tuning** tab and let some
water run. Set the thresholds (the *Derive thresholds* button puts them at 30 %
and 70 % of the swing), check that the *Rejected* counter stays at or near
zero, and adjust dwell time and minimum gap if needed:
[docs/tuning.md](tuning.md).

## 5. Check the volume per edge

Set *Volume per edge* to the value from step 0 and compare the device with the
meter's number rollers after a few hundred litres. If they drift apart, the
volume per edge is wrong or edges are being missed or doubled. Look at the
scope during a draw.

## 6. Document and open a pull request

Your meter folder:

```
meters/<vendor>-<model>/
├── README.md
├── cad/          OpenSCAD (or other parametric) source
├── stl/          exported parts
├── images/       renders
└── photos/       reference photos, metadata stripped: exiftool -all= *.jpg
```

The folder's `README.md` should contain:

- **Meter data**: vendor, model, register type, nominal flow (Q3), which
  module bay or interface, which original modules exist for it.
- **Disc**: layout (e.g. half chrome / half black), revolutions per m³,
  litres per edge.
- **Module bay**: what was measured and how, outline, sensor position,
  snap/clip details, anything that broke or surprised you.
- **Printing and assembly**: parts, orientation, filament, screws, steps.
- **Tested values**:

| | Value |
|---|---|
| R1 (LED series) | e.g. 560 Ω |
| R2 (emitter) | e.g. 1.56 kΩ |
| Dark level | e.g. ~500 mV |
| Bright level | e.g. ~2900 mV |
| Upper / lower threshold | e.g. 2200 / 1200 mV |
| Dwell | e.g. 80 ms |
| Minimum gap | e.g. 150 ms |
| Volume per edge | e.g. 500 ml |

Then add a row to the tables in [meters/README.md](../meters/README.md) and
the main [README.md](../README.md), and open a pull request. See also
[CONTRIBUTING.md](../CONTRIBUTING.md).

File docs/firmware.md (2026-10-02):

# Firmware

The firmware lives in [`firmware/`](../firmware/). It is written in C++20 on
ESP-IDF 6.0.1 and built with PlatformIO. Target is the ESP32-C6 Super Mini.
Components, internals and the full HTTP API are described in
[firmware/README.md](../firmware/README.md).

## Building and flashing

```bash
cd firmware
pio run -e supermini-c6                                    # build
pio run -e supermini-c6 -t upload --upload-port /dev/ttyACM0
pio device monitor
```

* **Plug the board straight into the computer**, not through a chain of USB
  hubs. Behind hubs the C6 can go into a brownout loop while flashing.
* The flash size is pinned to **4 MB** in `platformio.ini`. Without that the
  upload writes an 8 MB header and the bootloader stops with an assert.
* After the first flash, updates go over the air: use *System* in the web
  interface, or run

  ```bash
  curl -X POST -H 'Content-Type: application/octet-stream' \
       --data-binary @.pio/build/supermini-c6/firmware.bin \
       http://192.168.1.50/api/v1/ota
  ```

  A new image runs on probation and is only kept once it has proven itself,
  see [Updates and rollback](#updates-and-rollback).
* **Version:** set by hand in `firmware/version.txt`. In a git checkout,
  `git describe` takes its place.

## First start

No credentials are compiled in. Without WiFi credentials the device opens its
own open network (no password) with a captive portal. Enter WiFi and,
optionally, MQTT there. Once the device has joined your WiFi, the setup
network stays up for another 120 s, so the phone that set it up can still read
the new address, and then closes.

The setup network is named after the device: `flowtick-xxxxxx` (the last three
bytes of the MAC) on a new device, or the name you gave it. You can change
that name, which is also the hostname, under *Settings*, for example to
`flowtick-garden`. On the home network the device announces itself via mDNS,
so `http://flowtick-garden.local` works as well as the IP address on systems
that resolve `.local` names.

Home Assistant identifies the device by `water-meter-xxxxxx`, an ID from the
time before the project was renamed. It is kept so that existing entities
survive the rename.

## Web interface

Four tabs:

| Tab | Content |
|---|---|
| **Meter** | reading, flow, continuous-flow indicator, *Water draws* (edge log grouped into draws, CSV export, clear) |
| **Tuning** | live oscilloscope of the raw signal, Current/Min/Max/Swing/Rejected, thresholds, edge filter, volume per edge |
| **Settings** | *Taking the adapter off* (pause counting), *Match the mechanical register*, WiFi, MQTT, *Radio* (transmit power), *Time* (time server and timezone), device name, password protection |
| **System** | status LED legend, firmware update, status, restart, factory reset |

Every tab has its own address (`#meter`, `#tuning`, `#settings`, `#system`), so
you can bookmark one directly. Top right, a five-bar indicator shows the WiFi
signal strength, with the dBm value in the tooltip, plus the MQTT state and the
firmware version.

### Changing WiFi

*Settings → WiFi* opens a dialog with the networks in range. Credentials are
**tested first, then stored**:

* **From the setup network:** the device joins the new network as a trial,
  reports success and its new IP in the dialog, stores the credentials and
  restarts after 30 s. The page then redirects to the new IP.
* **From an existing network:** the device tries the new network, returns to
  the old one to report its new IP, and then switches for good. The two
  networks may be on different subnets. The page redirects to the new IP.

Wrong credentials are never stored, so the device cannot lock itself out.
While a successful change is still being applied, a second one is refused
with "still being applied; try again shortly", so it cannot slip in untested.

The station runs at 20 MHz with WiFi 6 (802.11ax) enabled: on 40 MHz the C6
falls back to WiFi 4, and a water meter needs reach, not throughput.

### Transmit power

*Settings → Radio* sets the transmit power in dBm (0 = maximum). **Apply**
takes effect immediately, without a restart, and is stored. Lower it as far as
reception allows. After a brownout, the firmware steps it down by itself.

### Time

*Settings → Time*: the time server defaults to `pool.ntp.org`. A built-in
server always stands behind it (`time.cloudflare.com`, or `pool.ntp.org` when
that is already the configured one). If you leave the field empty, both slots
use built-in servers. The clock syncs every hour.

The device counts in UTC. The timezone, picked from a list (default
Europe/Berlin), only sets how times are shown in the web interface. The CSV
export and MQTT stay in UTC.

## How edges are counted

The sampler reads the ADC (GPIO1) at 100 Hz, as the median of 8 readings. The
edge detector does more than hysteresis, so that neither interference nor
taking the case off makes up water:

1. **Hysteresis.** Two thresholds; for the Allmess meter, 2200 / 1200 mV.
2. **Dwell** (`dwell_ms`, 80 ms). A crossing only counts once the signal has
   stayed beyond the threshold this long. Shorter ones are discarded and
   counted as *Rejected*.
3. **Minimum gap** (`min_edge_ms`, 150 ms). Edges closer than this are
   physically impossible and wait. A crossing that falls back before the gap
   has passed is discarded and counted as *Rejected* too.
4. **Plausibility.** Outside 50–3250 mV means a rail: the sensor is loose, the
   LED is dead, or light gets in. After 0.5 s of this the detector goes to
   **Fault** and stops counting. After 2 s of plausible signal comes
   **Resync**. The detector only decides which sector it sees once the signal
   has been clearly below the lower or above the upper threshold for the dwell
   time. In between, for example while the case is being put back or when the
   disc has stopped on the boundary, nothing is decided. At worst one edge
   (0.5 L) is missed once, but a phantom edge cannot occur.
5. **Pause.** A button in the web interface, or `POST /api/v1/meter/pause`,
   for example to take the case off. Resuming also goes through Resync.

The detector also starts in Resync, so a restart never counts a phantom edge.

The mode (`run`, `resync`, `fault`, `paused`) and the number of rejected
crossings are in `/api/v1/info` and in the Tuning tab. Tuning itself is
covered in [tuning.md](tuning.md).

## Keeping the reading across restarts

The reading is a `uint64` in millilitres. It is written to NVS **every minute
if it has changed**, not on every edge, which would wear out the flash within
months. A power cut costs at most a minute of consumption. Even with water
running day and night, that is about two erase cycles per NVS page and day,
roughly 135 years to the rated 100 000.

Before every deliberate restart (OTA, restart button, recovery), the reading
is saved as well. Home Assistant treats a reading that goes backwards
(`total_increasing`) as a meter swap.

Thresholds and the volume per edge are stored immediately. They rarely change,
and losing one costs more than a flash write.

**Matching the register:** *Settings → Match the mechanical register* takes the
reading in m³ as an absolute value, not a correction. Sending it twice still
gives the right value.

## Updates and rollback

A new image starts **on probation**. It is kept only once it has shown,
by itself:

* 30 s up without a crash or watchdog reset,
* the sampler still taking samples,
* a network: connected to your WiFi when credentials are stored (the setup
  network only counts on a device that has none, since an image that can no
  longer join your WiFi is out of reach at the meter),
* its own web server answering, checked over loopback (127.0.0.1), so an image
  that could not be updated again is never kept.

Uploaded from *System → Firmware update*, the page also waits for the device
to come back and **confirms** the new image; both are needed, within 120 s.
Keep the page open until it reports the result: closed before it has
confirmed, the device rolls back once the 120 s are up. Uploaded with `curl`,
the self-test decides alone, within 60 s. A device whose WiFi credentials are
stored but whose home network is down while you update it, even over the setup
network, always rolls back: the new image has to show that it can join that
network. Whatever is still missing shows in `GET /api/v1/ota/status` under
`probation`. If time runs out, the device restarts into the previous firmware.

## Recovery and factory reset

Two ways back, for different situations:

| | How | Erases | Keeps |
|---|---|---|---|
| **BOOT button** | hold BOOT for 5 s while the device runs; the LED goes solid after the first second and stays on while the hold counts, flashes three times and the device restarts. Held while plugging in, BOOT enters download mode instead and erases nothing | WiFi credentials and the web interface password | everything else |
| **Factory reset** | *System* tab, *Erase all settings* | WiFi, password, device name, MQTT, transmit power, time server and timezone | meter reading, tuning (thresholds, edge filter, volume per edge), edge log |

The BOOT button is the way in when the device no longer joins your WiFi or
the password is lost: afterwards it opens its setup network again, under its
current device name. A hold
that is released early changes nothing. The factory reset leaves the meter
counting, because losing the reading or the tuning costs more than entering
WiFi again.

## Edge log

Every edge also goes into its own flash partition, `edgelog`. It is 256 KB and
holds ~32 000 edges, which is ~16 m³ at 0.5 L per edge. The log is a ring of
4 KB sectors with 8-byte entries, append-only, each entry with a CRC. A sector
is only erased when the ring comes back round to it. Wear is spread evenly,
and a power cut in the middle of a write spoils at most one entry.

Entries store the uptime. Once SNTP has set the clock, a per-boot epoch entry
is added, so edges from before the time sync also get a real time.

*Meter → Water draws* groups edges less than 60 s apart into draws (start,
duration, litres), over the whole log. *Download CSV* writes the raw log, one
row per edge with its time (UTC), so it can be grouped differently elsewhere.

## Status LED

One LED (GPIO15). The pattern repeats every **10 s**; count the flashes:

| Pattern | Meaning |
|---|---|
| 1 flash | all good, online |
| 2 flashes | WiFi configured but not connected |
| 3 flashes | online, but the sensor is in Fault |
| plus 1 short flash per edge | water is flowing |
| solid | booting / BOOT held (erase armed) |
| even 5 Hz | setup network active |
| mostly on, short gaps | firmware update, do not unplug |
| 10 Hz | fatal error |

The legend is also in the System tab. The green BAT LED on some Super Mini
boards hangs off the charger circuit and cannot be switched off in firmware.
Desolder it if it bothers you.

## Live oscilloscope

The Tuning tab shows the raw signal in real time. Both thresholds appear as
dashed lines, every detected edge as a vertical line, and rejected crossings
are marked at the top. The stream (50 Hz) only runs while the tab is open, and
starts empty each time you open it.

To keep it smooth:

* Samples go out in bundles of up to 10 (100 ms), on a socket with
  `TCP_NODELAY`.
* The page plays back on its own clock, 300 ms behind the device, and draws
  along the time axis rather than by arrival.
* WiFi power save is off while the scope runs.
* A watchdog reconnects after 3 s of silence.

The web server closes clients it cannot send to (3 s timeout, TCP keepalive),
so a stuck browser tab blocks neither other clients nor an OTA update.

## MQTT

Under *Settings → MQTT*:

* **Publish to a broker:** switches MQTT on or off. The settings are kept
  either way.
* **Broker:** host, `mqtt://` or `mqtts://` (the default port follows: 1883 /
  8883), and an optional client ID.
* **Server certificate** (mqtts only):
  * **Public authorities (built in):** the firmware carries Mozilla's root CA
    list (~140 roots). This fits brokers with a certificate from Let's
    Encrypt or a cloud broker. The host must then be the name in the
    certificate, not an IP.
  * **Own CA certificate:** paste a PEM, for a self-signed broker or your own
    CA.
  * **Do not check:** encrypted, but anybody could pose as the broker.
* **Login:** optional. When it is off, the device connects anonymously and
  deletes any stored credentials on Save. A stored password is kept as long
  as the field stays empty.
* **Topics:** the topic root, which defaults to `flowtick/<device name>`,
  e.g. `flowtick/flowtick-garden`; set it to something shorter if you like.
* **Home Assistant discovery:** on/off, plus the discovery prefix. Switched
  off, the device removes its entities from Home Assistant on the next
  connect.

Published topics, all retained, with `<base>` the topic root (here set to
`flowtick/garden`):

| Topic | Content |
|---|---|
| `<base>/status` | `online` / `offline`; the last will says `offline` |
| `<base>/state/total` | reading in m³ |
| `<base>/state/flow` | flow in L/min (10 s window) |
| `<base>/state/continuous_flow` | `On` / `Off` |
| `<base>/sensor` | status JSON, every minute |

**Availability.** `<base>/status` is `offline` while the edge detector is in
**Fault** (0.5 s implausible, back after 2 s steady). `resync` and `paused`
count as `online`, because the reading stays valid. The status LED (3 flashes)
follows the same rule. If the device disappears altogether, the broker sends
its last will, `offline`, after about 45 s (MQTT keepalive 30 s).

On every connect the device also publishes empty retained payloads to the
topics earlier firmware used (`<base>` itself and `<base>/state/mv`,
`edges`, `status`), which removes them from the broker.

**Status JSON** on `<base>/sensor`:

```json
{"mode":"run","firmware":"0.10.0","uptime_s":1234,"boot_reason":"power on",
 "free_heap":264820,"min_free_heap":255888,
 "network":{"hostname":"flowtick-garden","ssid":"MyWiFi","rssi_dbm":-67,
            "channel":6,"tx_power_dbm":17,"mac":"aa:bb:cc:dd:ee:ff",
            "ip":"192.168.1.50","netmask":"255.255.255.0",
            "gateway":"192.168.1.1","dns":"192.168.1.1"},
 "time":{"synced":true,"server":"pool.ntp.org","timezone":"Europe/Berlin"}}
```

## Web interface login

Off by default. With a password set, every page and API call needs it (HTTP
Basic auth). After 5 wrong attempts further logins are refused for 10 s,
which makes guessing slow without locking you out for long.

## Home Assistant

With discovery on, the device appears with these entities:

* **Meter reading**: `device_class: water`, `state_class: total_increasing`,
  in m³.
* **Flow**: in L/min.
* **Status** (diagnostic): its state is the detector mode, and its
  attributes are the JSON above. It stays readable when the sensor is in
  Fault, and becomes unavailable after 3 minutes without an update.
* **Continuous flow** (`binary_sensor`, `device_class: problem`).

For the **energy dashboard**, add the meter reading under *Settings →
Dashboards → Energy → Water consumption*.

### Automation ideas

* **Leak warning:** use **Continuous flow**. It turns *Problem* once edges
  with never 10 minutes of quiet between them span an hour, and 10 minutes
  without an edge reset it. The flow figure alone is no good for this: at
  0.5 L per edge and a 10 s window it is either 0 or ≥ 3 L/min, so a dripping
  tap never shows. Long garden watering triggers it too, so exclude that with
  a condition in the automation.
* **Burst pipe:** flow above a level that never occurs in the household.
* **Away:** any consumption above 2 L while nobody is home.
* **Sensor:** Status in `fault` for more than a few minutes.

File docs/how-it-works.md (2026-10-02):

# How it works

## The scanning disc

Many mechanical water meters have a small **scanning disc** in the register
next to the number rollers. It turns with the flow, and one part of it is
bright (chrome or white) while the rest is dark. It is there for the
manufacturer's own add-on modules, which read it optically and turn it into
pulses, M-Bus or radio telegrams.

flowtick-meter reads the same disc. It puts its own reflective sensor in the
module bay, in place of the vendor module:

The sensor over the chrome and the black sector, and the resulting signal

When the disc turns, the sensor sees a square wave: a high voltage over the
bright sector and a low voltage over the dark one. Every change from one to
the other is an **edge**, and every edge is a fixed amount of water.

**Example: Allmess EVK 3/110 +m.** The dial is marked `x0,0001`, so the disc
makes 1000 revolutions per m³, which is **1 L per revolution**. It is half
chrome and half black, so there are 2 edges per revolution, which makes
**0.5 L per edge**. The vendor pulse module only resolves 1 L. Details are in
[meters/allmess-evk-3-110-m](../meters/allmess-evk-3-110-m/README.md).

## Why not the vendor module

Vendor pulse modules work, but they run on a **glued-in lithium cell**. The
Allmess PM +m, for example, is rated for 13 years. Water meters have to be
replaced for recalibration every few years. On a 6-year cycle, that means
buying a new module every second meter swap, for the price of a whole
flowtick build several times over.

A mains-powered reflective sensor has no battery to run down. The module bay
is usually identical across a manufacturer's whole meter family, so a case you
have built once also fits the next meter.

The disc is read optically, not magnetically. Manufacturers avoid reed
switches because a magnet held against the meter could fool them. For us, it
means the sensor we need is just a simple reflective coupler.

## Signal chain

```mermaid
flowchart LR
  sensor["TCRT5000L"] --> adc["ADC<br/>GPIO1, 100 Hz<br/>median of 8"]
  adc --> det{{"Edge detector<br/>hysteresis, dwell,<br/>minimum gap,<br/>fault and resync"}}
  det --> total["Reading<br/>and flow"]
  total --> nvs[("NVS<br/>reading, every minute<br/>if it changed")]
  total --> log[("Edge log<br/>every edge with its time,<br/>in a flash ring")]
  total --> mqtt["MQTT<br/>Home Assistant discovery"]
  total --> web["Web UI<br/>live scope, settings, OTA"]
```

* **Sensor.** An IR LED and a phototransistor in one package, the Vishay
  TCRT5000L. Two resistors set the LED current and the gain. They are chosen
  per meter, see [hardware.md](hardware.md#choosing-the-resistors).
* **ADC.** The ESP32-C6 samples at 100 Hz and takes the median of 8 readings
  per sample.
* **Edge detector.** Two thresholds with hysteresis. A crossing has to last
  80 ms, edges have a minimum spacing, and implausible signals pause counting.
  For example, the signal goes implausible when the case is taken off or light
  gets in. See [firmware.md](firmware.md#how-edges-are-counted).
* **Reading.** The total in millilitres is saved to flash every minute if it
  has changed, and before every deliberate restart. Every edge also goes into
  an append-only log that does not wear out the flash.
* **Outputs.** MQTT with Home Assistant discovery, and a web interface with a
  live oscilloscope for tuning.

## Alternatives, and why this one

| Approach | Upside | Downside |
|---|---|---|
| **Vendor pulse module** | plug in, done | glued-in battery, buy again with every few meters; often only 1 L resolution |
| **Vendor M-Bus module** | absolute reading from the meter | needs an M-Bus master and the vendor's programming tools; expensive |
| **Vendor wireless M-Bus** | no wires | telegrams are often encrypted, with the key only from the utility; some have no open-source decoder (e.g. Itron/Allmess EquaScan has no wmbusmeters driver) |
| **Camera + OCR** ([AI-on-the-edge-device](https://github.com/jomjol/AI-on-the-edge-device)) | reads the real absolute register, nothing touches the meter | lighting and ROI tuning are fiddly, coarser resolution, a camera mounted in front of the meter for good |
| **Magnetic / inductive sensors** | work on meters with a magnet or metal target | many modern meters have neither, on purpose |
| **Reflective sensor on the scanning disc** (this project) | no battery, sub-litre resolution, reusable across a meter family | needs a case for the module bay and a one-time tuning of two resistors |

A camera is a serious alternative if you are not allowed to use the module
bay. If the meter belongs to the utility or the landlord, putting your own
hardware into it can count as tampering with a calibrated device, so ask
first.

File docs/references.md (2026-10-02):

# References

## Allmess (first supported meter)

* [Data sheet System V and MK](https://www.allmess.de/fileadmin/multimedia/alle_Dateien/DB/DB_System%20V%20und%20MK_01_23.pdf)
  (German): the `+m` module register, shared across the meter family.
* [Tender text EVK/W 3/110-V +m](https://www.allmess.de/fileadmin/multimedia/alle_Dateien/AS/AS_P0850_EVK%20V_TS1221.pdf)
  (German)
* [Tender text communication modules](https://www.allmess.de/fileadmin/multimedia/alle_Dateien/AS/AS_P0821_Kommunikationsmodule_TS1221.pdf)
  (German): PM +m pulse, BM +m M-Bus, EquaScan wMIU RF.
* [Allmess downloads](https://www.allmess.de/download/)

## Components

* [Vishay TCRT5000(L) data sheet](https://www.vishay.com/docs/83760/tcrt5000.pdf):
  dimensions, peak response at 2.5 mm, current transfer ratio.
* [ESP32-C6 Super Mini: pinout and specs](https://www.espboards.dev/esp32/esp32-c6-super-mini/)
* [ESP-IDF: ADC on the ESP32-C6](https://docs.espressif.com/projects/esp-idf/en/latest/esp32c6/api-reference/peripherals/adc/index.html)
* [CNY70 reflective coupler explained](https://www.strippenstrolch.de/1-2-12-der-reflexkoppler-cny70.html)
  (German): a good walk-through of how to wire a reflective sensor.

## Similar projects with a reflective sensor

* [hugokernel/esphome-water-meter](https://github.com/hugokernel/esphome-water-meter):
  TCRT5000 on a reflective disc, ESPHome.
* [geertmeersman/energie-meter](https://github.com/geertmeersman/energie-meter):
  water and gas, ESPHome.
* [xperseguers/esphome-watermeter](https://github.com/xperseguers/esphome-watermeter)
* [anas-ivs/ESPHome-Water-Meter](https://github.com/anas-ivs/ESPHome-Water-Meter)
* [JN0V/WaterMeter](https://github.com/JN0V/WaterMeter): ESP32 and MQTT without
  ESPHome.

## Other ways to read a meter

* [jomjol/AI-on-the-edge-device](https://github.com/jomjol/AI-on-the-edge-device)
  ([documentation](https://jomjol.github.io/AI-on-the-edge-device-docs/)):
  an ESP32-CAM reads the number rollers.
* [wmbusmeters](https://github.com/wmbusmeters/wmbusmeters): wireless M-Bus
  decoding ([drivers](https://github.com/wmbusmeters/wmbusmeters/tree/master/drivers/src)).
  * [Issue #346](https://github.com/wmbusmeters/wmbusmeters/issues/346): Itron/Allmess
    EquaScan, closed without a driver.
  * [Home Assistant forum: EquaScan wMIU RF](https://community.home-assistant.io/t/equascan-wmiurf-water-meter/826448)
* [libmbus](https://github.com/rscada/libmbus): wired M-Bus.

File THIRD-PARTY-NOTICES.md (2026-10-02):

# Third-party notices

flowtick-meter is licensed under the Apache License, Version 2.0; see
[LICENSE](LICENSE). Everything in this repository (firmware source, CAD
models, documentation and images) is under that licence.

The **firmware images** are not only this source. Building links in the ESP-IDF
framework and the components listed below, so a released `.bin` carries other
people's code under their licences. This file records what and whose, which is
what those licences ask for in return.

Nothing here is vendored into the repository. The components are fetched at
build time by the IDF component manager, pinned by
[`firmware/dependencies.lock`](firmware/dependencies.lock), and the framework
comes from the PlatformIO platform pinned in
[`firmware/platformio.ini`](firmware/platformio.ini).

## What the images contain

| Component | Version | Licence | Source |
| :--- | :--- | :--- | :--- |
| ESP-IDF | 6.0.1 | Apache-2.0 | [espressif/esp-idf](https://github.com/espressif/esp-idf) |
| FreeRTOS kernel | 10.5.1 | MIT | bundled with ESP-IDF |
| lwIP | 2.2.0 | BSD-3-Clause | bundled with ESP-IDF |
| Mbed TLS | 4.0.0 | Apache-2.0 (see below) | bundled with ESP-IDF |
| Wi-Fi and PHY libraries | with ESP-IDF 6.0.1 | Apache-2.0 (see below) | [espressif/esp32-wifi-lib](https://github.com/espressif/esp32-wifi-lib) |
| CA certificate bundle | with ESP-IDF 6.0.1 | MPL-2.0 (data) | Mozilla root store, via ESP-IDF `esp_crt_bundle` |
| cJSON | 1.7.19~2 | MIT | [espressif/cjson](https://components.espressif.com/components/espressif/cjson) |
| mDNS | 1.13.1 | Apache-2.0 | [espressif/mdns](https://components.espressif.com/components/espressif/mdns) |
| esp-mqtt | 1.1.0 | Apache-2.0 | [espressif/mqtt](https://components.espressif.com/components/espressif/mqtt) |

All of these are compatible with distributing the combined firmware under
Apache-2.0.

**Mbed TLS** is offered under Apache-2.0 *or* GPL-2.0-or-later. The Apache-2.0
option is the one that applies here.

**The Wi-Fi and PHY libraries** are shipped by Espressif as pre-compiled
binaries under Apache-2.0. The licence is permissive, but their source is not
published, so they cannot be rebuilt from source the way everything else can.

**The CA certificate bundle** is the list of root certificates from Mozilla's
CA store, which ESP-IDF converts and embeds for TLS server verification (used
by `mqtts://` with "public authorities"). The certificate data is distributed by
Mozilla under the Mozilla Public License 2.0; it is embedded unmodified.

## Where the firmware came from

The infrastructure components (networking, configuration storage, web server,
MQTT, OTA with rollback, watchdog, coredump and BOOT-button recovery) were
taken from the author's own `bsh-dbus-idf` project and adapted. Only the
author's own code was taken; none of that project's third-party code is part
of this repository.

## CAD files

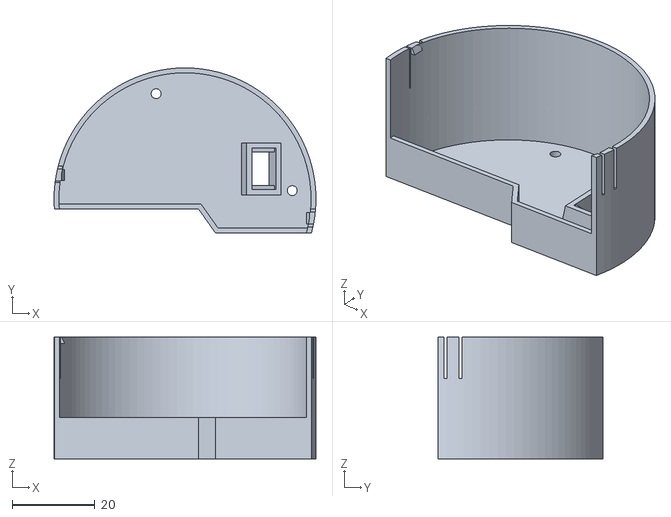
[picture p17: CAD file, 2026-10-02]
meters/allmess-evk-3-110-m/stl/adapter.stl
63.5 x 40.0 x 29.5

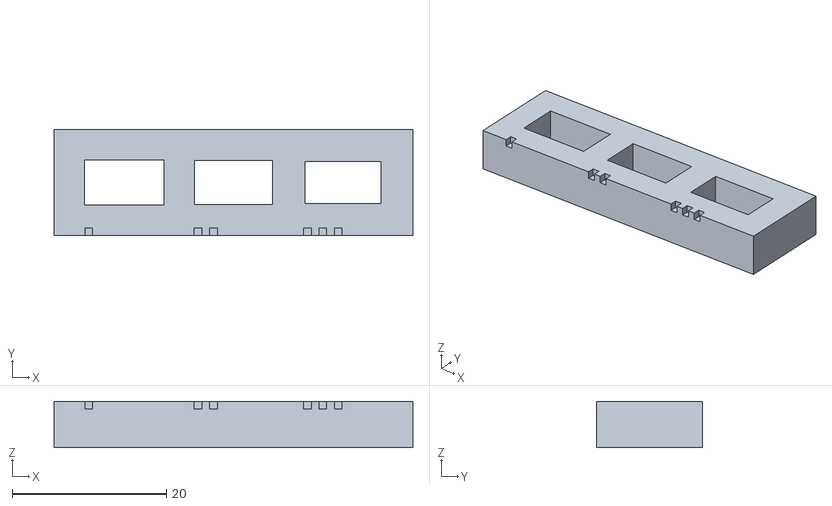
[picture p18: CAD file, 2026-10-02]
meters/allmess-evk-3-110-m/stl/slot-test.stl
46.6 x 13.8 x 6.00

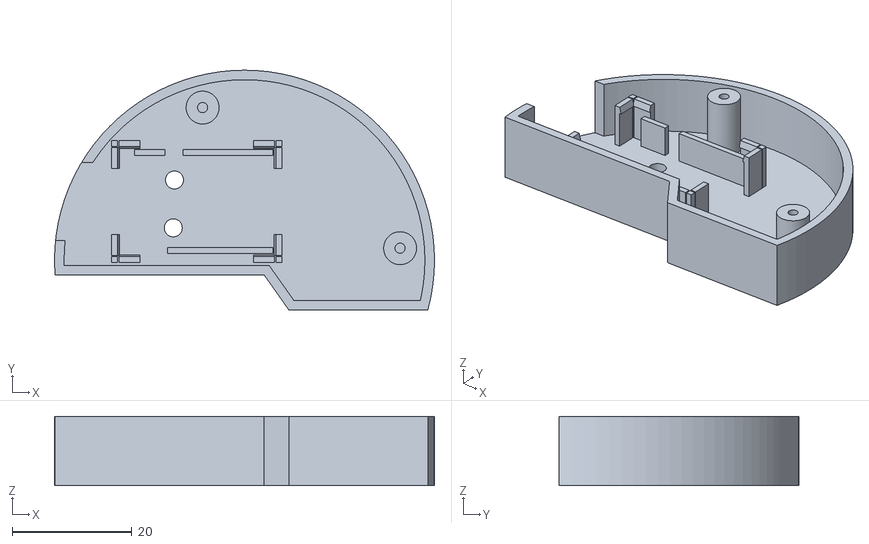
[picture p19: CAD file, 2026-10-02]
meters/allmess-evk-3-110-m/stl/cap.stl
63.5 x 40.0 x 11.6

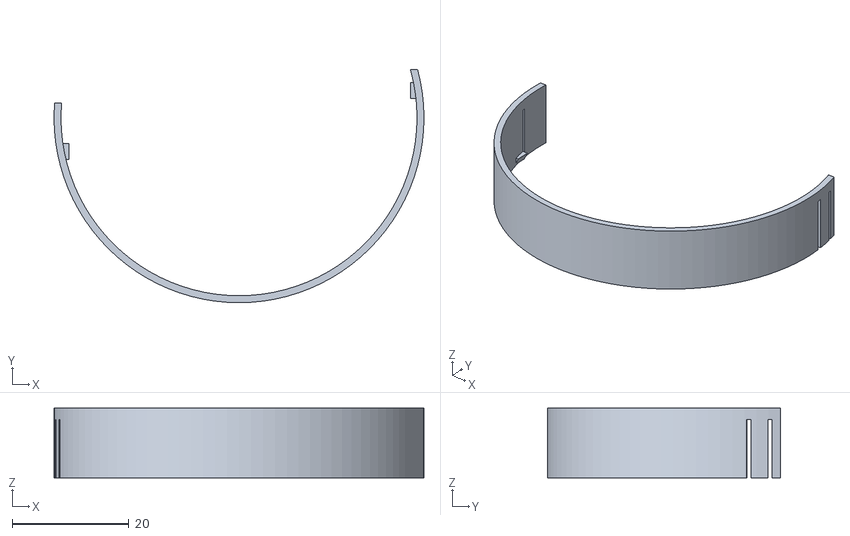
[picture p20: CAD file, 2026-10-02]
meters/allmess-evk-3-110-m/stl/snap-test.stl
63.5 x 40.0 x 12.0

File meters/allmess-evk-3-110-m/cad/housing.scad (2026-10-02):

// flowtick-meter case for the Allmess EVK 3/110 +m water meter: a printed
// replacement for the blank module ("Leermodul") of the +m module bay that
// carries the TCRT5000L over the scanning disc and the ESP32-C6 Super Mini in
// front of it.
//
// Two parts, both printable without support:
//   adapter  - the blank-module shape with the pocket over the scanning disc
//              and a slot for the sensor. Print front face down.
//   cap      - the compartment for the Super Mini. Print lid down.
// They are joined with two M2 self-tapping screws.
//
// Coordinates, looking at the meter from the front:
//   x  to the right, y up, origin in the centre of the round meter head
//   z  towards you; z = 0 is the back rim that sits against the meter
//
// Measured on a removed blank module unless marked "guess"; the outline and
// the snap tongues come from a 300 dpi flatbed scan (0.085 mm/px), see
// ../photos/ and ../README.md.
//
// Copyright 2026 Jonas Brüstel
// SPDX-License-Identifier: Apache-2.0

part = "both";   // "adapter", "cap", "both" (preview, assembled), "print" (both, laid out for printing),
                 // "slot-test" (three sensor slots to find the press fit before printing the adapter),
                 // "open" (preview without the cap, to see board and sensor),
                 // "snap-test" (the rim with the snap tongues, to try the fit on the meter)

$fn = 96;

/* [Blank module] */
R            = 63.5 / 2;  // outer radius
D0           = 23.5;      // depth of the original blank module, back rim to front face
// Ours is deeper: the front plate moves out by lift, and in the room gained
// behind it sits the sleeve that holds the sensor -- ending where the floor of
// the original was, under which the window sits. Rim, tongues and inner wall stay
// where they were relative to the meter.
lift         = 6.0;
D            = D0 + lift;
wall         = 1.2;       // original is 1.0 (scan); a little more for PETG
front        = 1.6;       // front plate
edge_y       = 2.5;       // the straight edge sits this far ABOVE the centre -- more than a half disc (scan)
// The nose under the pocket, filling the step in the name plate (scan and
// calipers agree): a chamfer from x0 on the straight edge up to x1, then flat
// at nose_h above the edge until it meets the round.
nose_x0      = 3.3;
nose_x1      = 7.4;
nose_h       = 5.8;
// Only the round runs the full depth and sits on the meter. The other walls
// hang from the front and stop short (side-view scan):
straight_h   = 14.5 + lift;  // the inner straight wall, from the front face; ends 9 mm above the rim as on the original
inner_wall_on  = false;   // off: the rim along the edge is enough and the wall gets in the way when fitting
inner_wall_gap = 1.0;     // gap between the rim along the edge and the inner wall (the original has ~3 mm)
nose_depth   = 4.0 + lift;  // the nose is only a lip at the front (original ~3.5), grown with lift
edge_lip     = 4.0 + lift;  // the rim along the straight edge, the chamfer and the nose, front plate
                            // included: 4 mm, plus lift so it ends where it did before
// Three ribs inside at the bottom of the round, 22 mm high from the front,
// thinning towards the rim; 3 mm apart, 1.9 mm thick at the base.
ribs_on      = false;     // off for the first print; switch on if the adapter wobbles on the register
ribs_x       = [-4.9, 0, 4.9];
rib          = [1.9, 1.0, 2.0, 22];  // base thickness, tip thickness, radial depth, height

/* [Pocket over the scanning disc] */
pocket_d     = 25;        // inner diameter
pocket_wall_h = 18;       // the pocket is an open cup under the front plate; wall height from its inside.
                          // The window of the scanning disc reaches into it from behind.
// Off by default: on the original it shields the PM module's optics and centres
// the module on the window. Here the black housing keeps the light out and the
// snap tongues locate it -- and with 0.2 mm of play a slightly misplaced cup
// would sit on the window and keep the adapter from seating.
pocket_wall  = false;
pocket_clear = 0.4;       // added to the diameter
// Centre of the pocket = centre of the scanning disc, from a circle fit to
// the (blurred) pocket wall in the rim-side scan, 70 points, rms 0.27 mm; the
// fitted radius 12.9 mm at the wall centre gives the measured inner 25 mm.
// It sits close under the straight edge, which is why the window pokes up
// into the step of the name plate and why the module has its nose.
pocket_c     = [17.83, -2.79];

/* [Sensor: Vishay TCRT5000L] */
// Vishay datasheet 83760: 10.2 +0.1/-0.2 x 5.8 +0.1/-0.2, 7.0 +-0.2 to the
// top of the lens domes. Full cross-section only over the 3 mm next to the
// leads, tapering towards the lenses; two snap clips stand 3 mm off the lead
// side. Peak output at 2.5 mm, about 75 % at 5 mm.
tcrt         = [10.2, 5.8, 7.0];  // body, lenses on the -z face
// Undersize per side. Small on purpose: the part varies by 0.3 mm and FDM holes
// come out 0.1-0.2 mm small anyway. Find the value with part = "slot-test".
press        = 0.05;
sensor_dir   = -90;       // direction from the disc centre, degrees (0 = +x): straight down, the only
                          // side with room -- the round is close on the right, the board on the left
// The disc is about 18 mm across (meter photo), the red hub about 3 mm; the
// sensing spot, between the two lenses, should sit well inside the chrome /
// black sectors and clear of the hub.
sensor_off   = 4.5;       // from the disc centre along sensor_dir, lens axis radial, so both lenses look at the
                          // rotating sectors and the board fits beside the sensor, not above it
tilt         = 12;        // about the lens axis: moves the direct reflection off the window away from the phototransistor

/* [Compartment for the Super Mini] */
// Lying across, USB-C to the left (the free side; there is a wall on the
// right), the 5V pin row towards the straight edge, beside the sensor rather
// than above it. Held in the cap, parts side towards the lid: pushed in past
// small lips on four corner brackets, it rests against ribs hanging from the
// lid. The cap and the board come off the adapter as one.
board        = [26.04, 18.0, 1.0];  // length (x), width (y), thickness -- vendor drawing
board_pos    = [-21.0, -18.8];      // lower left corner; the USB-C end is at the left; clear of the straight wall
usb_over     = 1.3;       // how far the receptacle sticks out past the board edge
board_stand  = 5.3;       // lid to the top of the board: room for the USB-C plug overmould above the receptacle
bracket      = [3.5, 1.0];      // corner brackets hanging from the lid: leg length, wall
lip          = [0.3, 1.2];      // retaining lip at the bracket tips: reach under the board, ramp height (was 0.4 / 0.8, too stiff)
fit          = 0.2;       // play around the board in the brackets
cap_inner    = 10.0;      // board stand-off + board + the plug overmould reaching below it
lid          = 1.6;
cap_wall     = 1.6;
usb_notch    = [13, 10.0];  // width, height of the opening for the plug overmould

// Holes in the lid, positions from the vendor drawing (from the USB end /
// from the 5V edge of the board).
function on_board(from_usb, from_5v) = [board_pos.x + from_usb, board_pos.y + board.y - from_5v];
boot_pos     = on_board(9.3, 12.6);  // BOOT: hold to erase the WiFi settings
rst_pos      = on_board(9.1, 4.6);   // RST
button_d     = 3.0;

// The status LED needs no hole: it shines through the lid.

// Pin rows: 10 pads at 2.54 mm, centred on the board. 5V row from the USB end:
// 5V GND 3V3 20 19 18 15 14 9 8; other row: TX(16) RX(17) 0 1 2 3 4 5 6 7.
function pin_x(i) = (board.x - 9 * 2.54) / 2 + (i - 1) * 2.54;
wire_gap = 1.5;           // free on either side of a pad with a wire on it
// Stand-off ribs as [5V row?, from, to] along the board, from the USB end.
// 5V row: under 20 ... 8, leaving 5V/GND/3V3 free. Other row: under 16/17/0
// (from behind the status LED at the USB end) and 2 ... 7, a gap at GPIO1.
ribs = [
  [true,  pin_x(3) + wire_gap, board.x - 0.3],
  [false, 2.6,                 pin_x(4) - wire_gap],
  [false, pin_x(4) + wire_gap, board.x - 0.3],
];
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

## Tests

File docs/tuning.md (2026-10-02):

# Tuning and calibration

You do all of this in the device's web interface, without reflashing. Values
are stored in NVS right away and survive restarts and OTA updates.

| Setting | Where | Allmess EVK 3/110 +m |
|---|---|---|
| Upper / lower threshold | *Tuning* → *Thresholds* | 2200 / 1200 mV |
| Dwell, minimum gap | *Tuning* → *Edge filter* | 80 / 150 ms (default) |
| Volume per edge | *Tuning* → *Volume per edge* | 500 ml (default) |
| Meter reading | *Settings* → *Match the mechanical register* | from the number rollers |

The defaults in the firmware are the Allmess values. A factory reset leaves
you with a counting meter if your hardware matches that one.

---

## 1. Check the signal swing

1. Mount the case on the meter, connect the device to WiFi, open the web
   interface and go to **Tuning**. The scope shows the raw signal live at
   50 Hz. It also shows both thresholds as dashed lines and every detected
   edge as a vertical line.
2. Press **Reset min/max**.
3. Let water run until the disc has turned a few times. At 1 L per revolution
   a few litres are enough.
4. Read **Current**, **Minimum**, **Maximum** and **Swing**.

Tuning tab: one revolution on the Allmess meter, swing 2627 mV, no rejected crossings

This is what a good signal looks like: flat levels well apart, steep
transitions that cross both thresholds cleanly, one green edge line per
transition and **Rejected** at 0.

Aim for a swing of **at least 500 mV**, with the signal clear of both rails.
The Allmess example reaches this:

| | |
|---|---|
| dark sector | ~500 mV |
| bright (chrome) sector | ~2850–2990 mV |
| swing | ~2.4 V |

Problems at this stage are usually hardware:

* **Signal stuck high at ~3.1–3.3 V on both sectors.** The phototransistor is
  saturated. Raise R1 (less LED current) or lower R2.
* **Swing small, both levels low.** Not enough light comes back. Lower R1 or
  raise R2. Also check that the sensor is close to the window and looks at the
  disc.
* **Swing small, both levels in the middle.** The sensor is probably looking
  past the disc, or at the window's reflection.

See [hardware.md → Choosing the resistors](hardware.md#choosing-the-resistors)
for the procedure.

## 2. Set the thresholds

**Derive thresholds from swing** fills in 30 % and 70 % of the measured swing.
Nothing is stored until you press **Save**. There are two thresholds rather
than one because a single threshold makes the signal bounce at the transition,
and every edge then counts several times.

With 500 / 2900 mV that gives ~1220 / 2180 mV. The Allmess setup rounds these
to **1200 / 2200 mV**.

## 3. Edge filter

* **Dwell** (80 ms): a crossing only counts once the signal has stayed beyond
  the threshold this long. Shorter excursions, such as a flash of light or
  bounce at the transition, are counted as **Rejected** and marked at the top
  of the scope.
* **Min. gap** (150 ms): two edges closer than this are physically impossible,
  so the second one waits. On the Allmess meter, edges are 0.58 s apart at the
  overload flow Q4 = 3.1 m³/h.

**Rejected** should stay at 0 while water runs. If it climbs on real edges, a
threshold sits too close to one of the sector levels.

The firmware also checks plausibility. If the signal is outside 50–3250 mV for
more than 0.5 s, it goes to *Fault* and stops counting. After 2 s of steady
signal it resynchronises (*Resync*): it waits until the signal is clearly
beyond one threshold and takes that as the current sector, without counting
an edge. It does the same after every restart.

## 4. Volume per edge

This is a property of the meter, not of the sensor. Work it out once per meter
model:

1. **From the dial.** The scanning disc usually has its own scale in the
   register, for example `x0,0001` (m³ per revolution) or a marking like
   `1000.0x` (revolutions per m³). Each bright/dark pair of sectors on the
   disc gives 2 edges per revolution:

   ```
   ml_per_edge = 1000 × litres_per_revolution / edges_per_revolution
   ```

   Allmess: 1 L per revolution, half bright and half dark, so 2 edges per
   revolution and **500 ml**.

2. **Bucket test**, to check the result or when there is no scale. Note the
   reading, draw exactly 10 L (weigh it: 10 kg = 10.0 L), then read it again:

   ```
   ml_new = ml_current × 10.0 / (L_after − L_before)
   ```

   Expect a round value such as 250, 500 or 1000 ml. An odd value almost always
   means false edges, so go back to step 3.

Over days, the reading in the web interface should keep pace with the number
rollers.

## 5. Match the mechanical register

Read the number rollers and enter the value under **Settings → Match the
mechanical register**. The value is absolute, not a correction, so sending it
twice does no harm. On the Allmess meter the black digits `00044` and the red
ones `2670` make `44.2670`. You can also set it through the API; add
`-u admin:<password>` if a password is set:

```sh
curl -X POST http://192.168.1.50/api/v1/meter/total -d '{"m3": 44.2670}'
```

Read it while no water is running, so that the rollers and the device agree.

## Taking the case off

Press **Settings → Taking the adapter off → Pause counting** first. When you
resume, the device first checks which sector the sensor sees and only then
counts again, so putting the case back cannot add phantom litres. If you
forget to pause, the plausibility check catches most of it (Fault after
0.5 s), but a single edge can slip through.

## Ongoing checks

Once a year is enough, ideally when you read the meter for the yearly bill.
Compare the rollers with the web interface and set the reading again if
needed.

The reading is saved every minute if it has changed, and before every
deliberate restart, so a power cut costs at most one minute of consumption. If
the reading drifts steadily, either the volume per edge is wrong or the sensor
has moved. The edge log under **Meter → Water draws** helps narrow it down,
because every edge is in it with a timestamp.

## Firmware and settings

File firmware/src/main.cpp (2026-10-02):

/*
   flowtick-meter -- optical reader for water meters with a scanning disc,
   first for the Allmess EVK 3/110 +m. ESP-IDF firmware.

   A reflective sensor over the optical scanning disc of the +m module
   register. The disc turns in proportion to the flow and carries one bright
   and one dark sector; every bright/dark edge is a fixed volume.

   Infrastructure taken from the author's bsh-dbus-idf project -- network,
   configuration, MQTT, web interface and OTA are the same components.

   Copyright 2026 Jonas Brüstel
   SPDX-License-Identifier: Apache-2.0
*/

#include "board.h"
#include "diagnostics.h"
#include "indicator.h"
#include "probation.h"
#include "recovery.h"

#include "appcfg/Config.h"
#include "appmqtt/Mqtt.h"
#include "appnet/Net.h"
#include "appweb/Web.h"
#include "edgelog/EdgeLog.h"
#include "meter/Meter.h"

#include <cJSON.h>
#include <esp_app_desc.h>
#include <esp_chip_info.h>
#include <esp_flash.h>
#include <esp_idf_version.h>
#include <esp_log.h>
#include <esp_netif.h>
#include <esp_ota_ops.h>
#include <esp_system.h>
#include <esp_timer.h>
#include <esp_wifi.h>
#include <freertos/FreeRTOS.h>
#include <freertos/task.h>

#include <atomic>
#include <cinttypes>
#include <cstdio>

static const char *const TAG = "wm";

static appnet::State g_net        = appnet::State::Idle;
static bool          g_seen_edges = false;

static void log_banner() {
  const esp_app_desc_t *app = esp_app_get_description();

  esp_chip_info_t chip;
  esp_chip_info(&chip);

  uint32_t flash_size = 0;
  esp_flash_get_size(nullptr, &flash_size);

  ESP_LOGI(TAG, "flowtick-meter %s (%s %s)", app->version, app->date, app->time);
  ESP_LOGI(TAG, "ESP-IDF %s, %d core(s), rev v%d.%d, %" PRIu32 " MB flash", IDF_VER, chip.cores, chip.revision / 100,
           chip.revision % 100, flash_size / (1024 * 1024));
  ESP_LOGI(TAG, "Board %s, ADC on GPIO%d", board::NAME, board::PIN_ADC);
}

static void refresh_system_led() {
  using indicator::System;
  /* A network event or the first edge must not paint over "do not unplug"
     during an update, or over the erase warning while BOOT is held. */
  if (indicator::system() == System::Ota || indicator::system() == System::Wiping)
    return;
  switch (g_net) {
    case appnet::State::ApMode:
      indicator::set_system(System::ApMode);
      break;
    case appnet::State::Connected:
      indicator::set_system(g_seen_edges ? System::Nominal : System::Connected);
      break;
    default:
      indicator::set_system(System::Disconnected);
      break;
  }
}

/* The entities Home Assistant should create. Announced once at startup and
   never again: a water meter is always the same device with the same
   entities. */
static void announce_entities() {
  appmqtt::Description dev;
  dev.device_id    = appcfg::device_id();
  dev.device_name  = appcfg::device().name;
  dev.model        = "flowtick-meter";
  dev.manufacturer = "flowtick";
  dev.firmware     = esp_app_get_description()->version;

  appmqtt::Reading readings[4] = {};

  readings[0].id           = "total";
  readings[0].name         = "Meter reading";
  readings[0].unit         = "m³";
  readings[0].device_class = "water";
  /* total_increasing, not total: the reading only ever runs forward, so Home
     Assistant may treat a drop as a meter swap instead of negative
     consumption. That is exactly what happens when the meter is replaced. */
  readings[0].state_class = "total_increasing";
  readings[0].available   = true;

  readings[1].id          = "flow";
  readings[1].name        = "Flow";
  readings[1].unit        = "L/min";
  readings[1].state_class = "measurement";
  readings[1].icon        = "mdi:water";
  readings[1].available   = true;

  /* The raw signal and the edge count are for tuning, which the web page does
     better; Home Assistant gets one status entity with the device's own
     state as attributes instead. */
  readings[2].id              = "device";
  readings[2].name            = "Status";
  readings[2].entity_category = "diagnostic";
  readings[2].icon            = "mdi:information-outline";
  readings[2].json_state      = "mode";
  /* Published every minute; three missed ones and the device is gone. */
  readings[2].expire_after_s = 180;
  readings[2].topic          = "sensor";
  readings[2].available      = true;
  /* "status" was this entity under state/ for a day, then on the root. */
  dev.retired        = {"mv", "edges", "status"};
  dev.retired_topics = {""};

  readings[3].id   = "continuous_flow";
  readings[3].name = "Continuous flow";
  readings[3].kind = "binary_sensor";
  /* "problem": Home Assistant shows it as OK / Problem, which is what it is. */
  readings[3].device_class = "problem";
  readings[3].icon         = "mdi:water-alert";
  readings[3].available    = true;

  appmqtt::announce(dev, readings, 4);
}

/* The status entity: what the device itself is doing, as one JSON object. */
static std::string status_json() {
  const meter::State m = meter::state();
  cJSON             *o = cJSON_CreateObject();
  cJSON_AddStringToObject(o, "mode", meter::to_string(m.mode));
  cJSON_AddStringToObject(o, "firmware", esp_app_get_description()->version);
  cJSON_AddNumberToObject(o, "uptime_s", static_cast<double>(esp_timer_get_time() / 1000000));
  cJSON_AddStringToObject(o, "boot_reason", diagnostics::boot_reason());
  cJSON_AddNumberToObject(o, "free_heap", esp_get_free_heap_size());
  cJSON_AddNumberToObject(o, "min_free_heap", esp_get_minimum_free_heap_size());

  cJSON *n = cJSON_AddObjectToObject(o, "network");
  cJSON_AddStringToObject(n, "hostname", appcfg::device().name.c_str());
  cJSON_AddStringToObject(n, "ssid", appnet::ssid().c_str());
  cJSON_AddNumberToObject(n, "rssi_dbm", appnet::rssi());
  cJSON_AddNumberToObject(n, "channel", appnet::channel());
  const int tx = appcfg::tx_power_dbm();
  cJSON_AddNumberToObject(n, "tx_power_dbm", tx > 0 ? tx : appcfg::kTxPowerMaxDbm);
  uint8_t mac[6] = {};
  char    buf[24];
  if (esp_wifi_get_mac(WIFI_IF_STA, mac) == ESP_OK) {
    std::snprintf(buf, sizeof(buf), "%02x:%02x:%02x:%02x:%02x:%02x", mac[0], mac[1], mac[2], mac[3], mac[4], mac[5]);
    cJSON_AddStringToObject(n, "mac", buf);
  }
  esp_netif_t        *sta = esp_netif_get_handle_from_ifkey("WIFI_STA_DEF");
  esp_netif_ip_info_t ip  = {};
  if (sta && esp_netif_get_ip_info(sta, &ip) == ESP_OK) {
    std::snprintf(buf, sizeof(buf), IPSTR, IP2STR(&ip.ip));
    cJSON_AddStringToObject(n, "ip", buf);
    std::snprintf(buf, sizeof(buf), IPSTR, IP2STR(&ip.netmask));
    cJSON_AddStringToObject(n, "netmask", buf);
    std::snprintf(buf, sizeof(buf), IPSTR, IP2STR(&ip.gw));
    cJSON_AddStringToObject(n, "gateway", buf);
  }
  esp_netif_dns_info_t dns = {};
  if (sta && esp_netif_get_dns_info(sta, ESP_NETIF_DNS_MAIN, &dns) == ESP_OK && dns.ip.type == ESP_IPADDR_TYPE_V4) {
    std::snprintf(buf, sizeof(buf), IPSTR, IP2STR(&dns.ip.u_addr.ip4));
    cJSON_AddStringToObject(n, "dns", buf);
  }

  const appnet::Time t = appnet::time_info();
  cJSON             *c = cJSON_AddObjectToObject(o, "time");
  cJSON_AddBoolToObject(c, "synced", t.synced);
  if (!t.server.empty())
    cJSON_AddStringToObject(c, "server", t.server.c_str());
  cJSON_AddStringToObject(c, "timezone", appcfg::clock().tz_name.c_str());

  char *text = cJSON_PrintUnformatted(o);
  cJSON_Delete(o);
  std::string out = text ? text : "{}";
  if (text)
    cJSON_free(text);
  return out;
}

/* Values to MQTT, every 10 s from the main loop: reading, flow and the leak
   watch. Retained, so a consumer that connects later sees them at once. The
   status goes out once a minute, so uptime and heap stay current and Home
   Assistant can tell a vanished device. */
static void publish_readings(bool include_status) {
  const meter::State s = meter::state();

  char buf[32];

  appmqtt::Reading r;
  /* Always a value. An empty retained payload would erase the reading at the
     broker whenever the signal is briefly implausible -- whether it is current
     is what the availability topic says, not the value. */
  r.available = true;

  std::snprintf(buf, sizeof(buf), "%.4f", s.total_ml / 1000000.0);
  r.id    = "total";
  r.value = buf;
  appmqtt::publish(r);

  std::snprintf(buf, sizeof(buf), "%.1f", s.flow_lmin);
  r.id    = "flow";
  r.value = buf;
  appmqtt::publish(r);

  r.id    = "continuous_flow";
  r.value = s.continuous_flow ? "On" : "Off";
  appmqtt::publish(r);

  if (include_status) {
    r.id        = "device";
    r.value     = status_json();
    r.available = true;
    appmqtt::publish(r);
  }
}

extern "C" void app_main() {
  log_banner();

  /* NVS first: diagnostics steps the transmit power down after a brownout
     and has to be able to store that. */
  if (!appcfg::begin())
    ESP_LOGE(TAG, "Configuration storage unavailable -- settings will not survive a restart");

  diagnostics::begin();
  indicator::begin();
  indicator::set_system(indicator::System::Booting);
  indicator::tick(esp_timer_get_time());

  recovery::begin();

  appmqtt::begin();

  /* Before the sampler starts, so no edge can arrive before the log is ready. */
  edgelog::begin();

  appnet::begin([](appnet::State s) {
    g_net = s;
    refresh_system_led();
    appmqtt::on_network(s == appnet::State::Connected);
  });

  /* Set before the sampler starts: it reads these without a lock. Every
     sample goes to the scope while one is open, every edge to the LED and the
     log. Both run on the sampler task, which is why neither may block. */
  meter::set_sample_sink([](int mv, bool edge, int64_t t_us) { appweb::publish_sample(mv, edge, t_us); });
  meter::set_edge_sink([](int64_t t_us) {
    indicator::note_edge();
    edgelog::record(t_us);
  });

  meter::Config mc;
  mc.adc_gpio = board::PIN_ADC;
  mc.ir_gpio  = board::PIN_IR;
  if (!meter::begin(mc)) {
    ESP_LOGE(TAG, "Cannot start the meter -- halting");
    indicator::set_system(indicator::System::Fatal);
    for (;;) {
      indicator::tick(esp_timer_get_time());
      vTaskDelay(pdMS_TO_TICKS(5));
    }
  }

  announce_entities();

  appweb::begin(
      []() {
        const meter::State  st = meter::state();
        const meter::Tuning tu = meter::tuning();

        appweb::Status s;
        s.total_m3        = st.total_ml / 1000000.0;
        s.flow_lmin       = st.flow_lmin;
        s.edges           = st.edges;
        s.mv              = st.mv;
        s.mv_min          = st.mv_min;
        s.mv_max          = st.mv_max;
        s.online          = st.online;
        s.mode            = meter::to_string(st.mode);
        s.rejected        = st.rejected;
        s.continuous_flow = st.continuous_flow;
        s.flow_run_s      = st.flow_run_s;
        s.dwell_ms        = tu.dwell_ms;
        s.min_edge_ms     = tu.min_edge_ms;
        s.thr_hi_mv       = tu.thr_hi_mv;
        s.thr_lo_mv       = tu.thr_lo_mv;
        s.ml_per_edge     = tu.ml_per_edge;
        s.scope           = meter::scope();
        s.net_state       = appnet::to_string(g_net);
        s.ip              = appnet::ip();
        s.ssid            = appnet::ssid();
        s.rssi            = appnet::rssi();
        s.channel         = appnet::channel();
        s.board           = board::NAME;
        s.pin_adc         = board::PIN_ADC;
        s.pin_ir          = board::PIN_IR;
        s.pin_led         = board::PIN_LED_STATUS;
        s.led_inverted    = board::LED_ACTIVE_LOW;
        return s;
      },
      [](bool active) { indicator::set_system(active ? indicator::System::Ota : indicator::System::Booting); },
      appweb::MeterApi{
          .state_json  = meter::state_json,
          .tuning_json = meter::tuning_json,
          .set_tuning  = meter::set_tuning_json,
          .set_total =
              [](double m3, std::string *err) {
                if (meter::set_total_m3(m3))
                  return true;
                if (err)
                  *err = "Reading must be between 0 and 99999 m³";
                return false;
              },
          .reset_minmax = meter::reset_minmax,
          .set_paused   = meter::set_paused,
          .set_scope =
              [](bool on) {
                meter::set_scope(on);
                appnet::set_low_latency(on); // or the stream arrives in bursts
              },
          .edges =
              [](size_t limit, const std::function<bool(const std::string &)> &emit) {
                return edgelog::for_each(limit, [&](const edgelog::Edge &e) {
                  char b[40];
                  std::snprintf(b, sizeof(b), "[%lld,%d,%u]", static_cast<long long>(e.t_ms), e.synced ? 1 : 0,
                                static_cast<unsigned>(e.boot));
                  return emit(b);
                });
              },
          .clear_edges = edgelog::clear,
      },
      appweb::DiagnosticsApi{
          .health_json    = diagnostics::health_json,
          .coredump_size  = diagnostics::coredump_size,
          .read_coredump  = diagnostics::read_coredump,
          .erase_coredump = diagnostics::erase_coredump,
      });

  probation::begin();

  refresh_system_led();

  int64_t next_publish = 0;
  int64_t next_status  = 0;
  int64_t next_health  = 0;
  int64_t next_stats   = 0;

  for (;;) {
    const int64_t now = esp_timer_get_time();

    diagnostics::feed();
    meter::tick(now);
    recovery::tick(now);

    /* Recovery and the OTA hook hand the LED back by setting Booting. Repaint
       from the network state right away instead of waiting for it to change,
       which could take forever -- the LED would stay solid on. */
    if (indicator::system() == indicator::System::Booting)
      refresh_system_led();
    indicator::tick(now);

    probation::tick(now, g_net == appnet::State::Connected);

    /* Sensor health from the detector's debounced mode, not from a single
       sample: Fault needs 0.5 s of implausible signal and clears only after
       2 s of a steady one. Resync and a deliberate pause still count as
       healthy -- the reading stays valid. Checked often, published only on
       change (and on the availability topic's own refresh). */
    if (now > next_health) {
      next_health                = now + 100000;
      const meter::State st      = meter::state();
      const bool         healthy = st.mode != meter::Mode::Fault;
      appmqtt::set_meter_online(healthy);
      indicator::set_sensor(!healthy           ? indicator::Sensor::Garbage
                            : st.flow_lmin > 0 ? indicator::Sensor::Healthy
                                               : indicator::Sensor::Silent);
    }

    if (now > next_publish) {
      next_publish = now + 10000000;

      /* Once per boot, as soon as SNTP has answered: from then on every edge
         of this boot, earlier ones included, has a wall-clock time. */
      static bool epoch_logged = false;
      if (!epoch_logged) {
        const appnet::Time t = appnet::time_info();
        if (t.synced) {
          edgelog::set_boot_epoch(t.boot_epoch_ms);
          epoch_logged = true;
        }
      }
      const bool with_status = (now > next_status);
      if (with_status)
        next_status = now + 60000000;
      publish_readings(with_status);

      const meter::State st = meter::state();
      if (!g_seen_edges && st.edges > 0) {
        g_seen_edges = true;
        refresh_system_led();
      }
    }

    if (now > next_stats) {
      next_stats            = now + 300000000;
      const meter::State st = meter::state();
      ESP_LOGI(TAG, "Reading %.4f m³, %.1f L/min, %llu edges, signal %d mV (%d..%d)", st.total_ml / 1000000.0,
               st.flow_lmin, static_cast<unsigned long long>(st.edges), st.mv, st.mv_min, st.mv_max);
      ESP_LOGI(TAG, "Network: %s%s%s", appnet::to_string(g_net), appnet::ip().empty() ? "" : " ", appnet::ip().c_str());
      ESP_LOGI(TAG, "Heap %" PRIu32 " (min %" PRIu32 "), Boot: %s", esp_get_free_heap_size(),
               esp_get_minimum_free_heap_size(), diagnostics::boot_reason());
    }

    vTaskDelay(pdMS_TO_TICKS(5));
  }
}

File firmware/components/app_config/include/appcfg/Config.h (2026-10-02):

/*
   Persistent configuration in NVS.

   Everything the user can change at runtime lives here, so the firmware never
   has to be rebuilt to move to a different network or change a password.

   Copyright 2026 Jonas Brüstel
   SPDX-License-Identifier: Apache-2.0
*/

#pragma once

#include <cstdint>
#include <string>

namespace appcfg {

struct Wifi {
  std::string ssid;
  std::string password;
  bool        configured() const {
    return !ssid.empty();
  }
};

struct Auth {
  /* Off by default: a fresh device must be reachable to be set up at all, and
     the exposure is reading a water meter. The user turns it on and picks the
     password. */
  bool        enabled = false;
  std::string user    = "admin";
  std::string salt_hex;
  std::string hash_hex;
  bool        has_password() const {
    return !hash_hex.empty();
  }
};

/* Where decoded readings go, if anywhere.

   Off until a broker is entered, because the alternative -- guessing a hostname
   and retrying forever -- fills the log of a device nobody is watching. The
   topic root is derived from the device name when left blank, so two adapters
   in one house do not collide by default. */
struct Mqtt {
  bool enabled = false;

  /* Kept apart rather than as one URI string: a scheme, a host and a port are
     three different questions, and typing them into one field made two of them
     easy to get silently wrong. The URI is assembled on the way to the client. */
  bool        tls = false;
  std::string host;
  uint16_t    port = kPortPlain;

  /* Empty: the device name is used, which is what the broker saw before this
     was settable. */
  std::string client_id;

  /* Credentials are a deliberate choice, not an inference from a filled-in
     field: with this off the client connects anonymously and anything stored is
     cleared, so a half-typed user name cannot lock the device out of a broker
     that accepts anonymous clients. */
  bool        auth = false;
  std::string user;
  std::string password;

  /* Only meaningful with tls. Without a CA the connection is not verified at
     all, so the two are one choice: bring a certificate, or say plainly that
     the server is not being checked. */
  bool        tls_insecure = false;
  std::string ca_cert; // PEM

  std::string base; // empty: derive from the device name

  /* Announce the entities to Home Assistant, so it builds the device itself
   instead of needing a hand-written sensor for every reading. On by default:
   a broker in a house almost always has Home Assistant behind it, and a
   device that publishes values nothing displays is a puzzle rather than a
   feature. */
  bool discovery = true;
  /* Where Home Assistant listens for those announcements. Configurable because
     it is configurable there. */
  std::string discovery_prefix = "homeassistant";

  static constexpr uint16_t kPortPlain = 1883;
  static constexpr uint16_t kPortTls   = 8883;

  bool configured() const {
    return !host.empty();
  }
  /* mqtt://host:1883 -- what the client actually connects to. */
  std::string uri() const;
};

struct Device {
  /* Also used as the mDNS hostname and the MQTT client id. */
  std::string name;
};

/* Time server and timezone.

   The device counts in UTC; the timezone is for showing times, in the web
   interface and the log. Both are kept as the interface picked them: the IANA
   name for the browser, the POSIX rule for the C library, which knows no
   names. */
struct Clock {
  std::string server   = kDefaultServer; // empty: the built-in servers only
  std::string tz_name  = "Europe/Berlin";
  std::string tz_posix = "CET-1CEST,M3.5.0,M10.5.0/3";

  static constexpr const char *kDefaultServer = "pool.ntp.org";
};

bool begin();

Wifi wifi();
bool set_wifi(const std::string &ssid, const std::string &password);
bool clear_wifi();

Auth auth();
/* Stores a PBKDF2-HMAC-SHA256 digest with a fresh random salt. An empty
   password clears the stored credential and forces protection off. */
bool set_password(const std::string &user, const std::string &password);
bool set_auth_enabled(bool enabled);
bool verify_password(const std::string &user, const std::string &password);

Mqtt mqtt();
bool set_mqtt(const Mqtt &m);

/* The topic root actually in use: the configured one, or one derived from the
   device name when it is blank. */
std::string mqtt_base();

/* The client id actually in use: the configured one, or the device name when it
   is blank -- which is what a broker saw before this was settable. */
std::string mqtt_client_id();

Device device();
bool   set_device_name(const std::string &name);

/* Time server and timezone, see Clock. */
Clock clock();
bool  set_clock(const Clock &c);
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
